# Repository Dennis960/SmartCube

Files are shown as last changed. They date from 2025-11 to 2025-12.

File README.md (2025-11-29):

# SmartCube

SmartCube is a modular, connectable LED cube platform. Each module is a small PCB containing addressable LEDs and sensors; modules mechanically and electrically connect using pogo pins and neodymium magnets. This monorepo contains KiCad PCB sources, a CadQuery 3D-model generator (that uses KiCad STEP exports), and firmware for the microcontrollers used across modules.

<!-- ![SmartCube](assets/cube.png)

TODO: Add image, once the cubes arrive -->

## Key features

- Modular PCB-based cube modules with addressable LEDs and Hall sensors
- Electrical connection via pogo pins; mechanical coupling via neodymium magnets
- ESP32 used as a power/aggregation/controller cube
- PY32 microcontrollers used for individual LED modules
- CadQuery scripts that generate printable enclosures using KiCad STEP references

## Project Structure

- [PCB](./PCB): KiCad projects for the LED module, power supply module and pogo pin connectors, as well as helper scripts for panelization.

- [3DModel](./3DModel): CadQuery scripts to generate 3D models of the cube modules and enclosures, using KiCad STEP exports as references.

- [Firmware](./Firmware): CMake-based firmware for the PY32 microcontrollers used in the LED modules, with support for flashing via ST-Link and esp-idf-based firmware for the ESP32 power/controller module.

A devcontainer exists for development for the 3DModel and panelization.

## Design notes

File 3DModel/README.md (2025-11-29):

# 3DModel

Generate and export 3D models of the SmartCube modules and enclosures using CadQuery scripts.

It is recommended to use the provided devcontainer for development, which includes all necessary dependencies.

Run

```bash
python main.py
```

inside the src folder to generate the models. The generated STEP files will be saved in the output folder.

## Troubleshooting

In case there is an issue with loading the kicad STEP files, delete the contents of the models folder and re-run the script to regenerate them.

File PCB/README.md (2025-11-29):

# PCB

This folder contains the KiCad projects for the SmartCube LED module, power supply module, and pogo pin connectors. It also includes helper scripts for panelization of the PCBs for manufacturing.

The KiCad projects all use the same shared library located in the `libs` folder.

If having problems loading footprints or 3d models, make sure to add the symbol and CustomFootprints libraries in KiCad.

## Module

[./Module](./Module) contains the KiCad project for the main LED module PCB.

It includes addressable LEDs and Hall sensors.
Communication happens via PY32 microcontrollers using pogo pin connectors.

## Power Module

[./PowerModule](./PowerModule) contains the KiCad project for the power supply module PCB.

It provides 5V power to the cubes via pogo pin connectors.

At least one power module is required in a SmartCube assembly to provide power to the other modules.

## Pogo Pin Connectors

[./PogoConnectors](./PogoConnectors) contains the KiCad projects for the pogo pin connectors.

It is used to connect the modules both mechanically and electrically.

## Panelization

[./Panel](./Panel) contains scripts to panelize the PCBs for manufacturing. The panelization uses the kikit tool.

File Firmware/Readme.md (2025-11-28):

# Firmware

This project provides a CMake-based setup for building firmware for the PY32F0 microcontrollers. It also supports flashing via ST-Link.
It is taken from [https://github.com/decaday/py32f0-cmake](https://github.com/decaday/py32f0-cmake)

---

## Prerequisites

- **ARM GCC Toolchain** (`arm-none-eabi-gcc`) with `sudo apt install gcc-arm-none-eabi`
- **CMake** (≥3.13)
- **Make**
- **ST-Link utilities** (`st-flash` or `st-util`) with `sudo apt install stlink-tools`
- **Git** (to clone the repository)

---

## 1. Build Firmware Using CMake + Make

1. Generate Makefiles with CMake:

```bash
cmake -B build -S .
```

2. Compile the firmware:

```bash
make -C build
```

- Output firmware: `build/py32-cmake.elf` and `build/py32-cmake.bin`

---

## 2. Flash Firmware to the Board

Using **ST-Link**:

```bash
st-flash write build/py32-cmake.bin 0x8000000
```

- Replace `0x8000000` with your MCU’s flash base address if different.

Optional: use **st-util** for debugging with GDB:

```bash
st-util
```

---

## 3. VS Code Integration

This repository includes **VS Code tasks** and a **launch configuration** for convenience:

- **Tasks**: Automate building and flashing.
- **Launch configuration**: Debug firmware using GDB and ST-Link.

### Usage

1. Open the project in VS Code.
2. Use the **Command Palette → Run Task** to build or flash firmware.
3. Start `st-util` in a terminal for debugging:

```bash
st-util
```

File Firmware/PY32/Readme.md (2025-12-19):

# Firmware PY32

This project provides a CMake-based setup for building firmware for the PY32F0 microcontrollers. It also supports flashing via ST-Link.
It is taken from [https://github.com/decaday/py32f0-cmake](https://github.com/decaday/py32f0-cmake)

Have a look at [https://github.com/junglami/py32-platform/tree/main/Examples/PY32F002B/LL](https://github.com/junglami/py32-platform/tree/main/Examples/PY32F002B/LL) for example code using the LL drivers.
Have a look at [the official firmware package](https://www.puyasemi.com/download_path/%E5%BA%93%E5%87%BD%E6%95%B0%E4%B8%8E%E4%BE%8B%E7%A8%8B/MCU%20%E5%BE%AE%E5%A4%84%E7%90%86%E5%99%A8/PY32F002B_Firmware_V1.2.1.zi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) for examples using both the HAL and LL drivers.

---

## Prerequisites

See [InstallToolchain.md](InstallToolchain.md) for installation instructions of the ARM Embedded Toolchain.

- **CMake** (≥3.13)
- **Make**
- **ST-Link utilities** (`st-flash` or `st-util`) with `sudo apt install stlink-tools`
- **Git** (to clone the repository)

---

## 1. Build Firmware Using CMake + Make

1. Generate Makefiles with CMake:

```bash
cmake -B build -S .
```

2. Compile the firmware:

```bash
make -C build
```

- Output firmware: `build/py32-cmake.elf` and `build/py32-cmake.bin`

---

## 2. Flash Firmware to the Board

Using **ST-Link**:

```bash
st-flash write build/py32-cmake.bin 0x8000000
```

- Replace `0x8000000` with your MCU’s flash base address if different.

Optional: use **st-util** for debugging with GDB:

```bash
st-util
```

---

## 3. VS Code Integration

This repository includes **VS Code tasks** and a **launch configuration** for convenience:

- **Tasks**: Automate building and flashing.
- **Launch configuration**: Debug firmware using GDB and ST-Link.

### Usage

1. Open the project in VS Code.
2. Use the **Command Palette → Run Task** to build or flash firmware.
3. Start `st-util` in a terminal for debugging:

```bash
st-util
```

### Debug & Release
- Launch configs: The workspace includes launch configurations for both Release and Debug.
- Breakpoints: Use the Debug configuration to set and hit breakpoints during firmware execution.
- Note: Flashing and debugging can fail if the LEDs are set to full brightness; reduce LED brightness if you encounter issues or connect an external power source.

---

## 4. Timing Protocols

For detailed information about the communication protocols and timing specifications implemented in this firmware, refer to [cube_communication_protocol/main.pdf](cube_communication_protocol/main.pdf).

This document outlines:
- Protocol specifications for cube communication
- Timing requirements and constraints
- Signal timing diagrams
- Communication handshake procedures

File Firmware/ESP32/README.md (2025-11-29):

# Firmware ESP32

This project contains the firmware for the ESP32 microcontroller used in the SmartCube platform. It is built using the esp-idf framework.

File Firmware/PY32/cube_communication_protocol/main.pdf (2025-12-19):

## 1 Timing protocols

The smart cubes communicate using a custom protocol over two data lines. Each cube has two data lines, D1 and D2. The data lines are only used for communication between cubes. Note that the cube’s data lines are inverted, meaning D1 of cube A is connected to D2 of cube B and vice versa.

### 1.1 Announcement

The announcement is used to connect a new cube inside a powered grid of cubes. The new cube will announce its presence to one side, starting at the first side (top). If another cube is present at that side, it will acknowledge the announcement of the new cube and a handshake will be performed. During the handshake, both cubes will check both their data lines for connection.
If presence is not acknowledged or the handshake fails, the new cube will retry the announcement on the next side.
The following timing diagram shows the digital signals. The Bus in the following diagram represents the actual state of the data lines of cube A. The data lines of cube A and cube B show their respective internal signals. A state of high impedance implies that the pin for that cube is set as input.

Bus 1

Bus 2

Cube A D1

ack presence

Cube A D2

ack handshake

Cube B D2

complete handshake

Cube B D1

announce

init handshake

Note

delay ≤ 10 ms

1

### 1.2 Data transfer (initiation)

When two cubes are successfully connected, they are in the idle state. Either cube can initiate data transfer to the other cube by asking for a communication. If the data initiation process is successful, the cube that asked for communication can start sending data.
The first byte of data sent is always the length of the data packet in bytes. The next bytes are the actual data bytes.
If the data specifies that a response is expected, the receiving cube will send a response packet back to the sender. Else the communication is finished and the cubes return to idle state.
The following timing diagram shows the digital signals. The Bus in the following diagram represents the actual state of the data lines of cube A. The data lines of cube A and cube B show their respective internal signals. A state of high impedance implies that the pin for that cube is set as input.

Bus 1

Bus 2

Cube A D1

Cube A D2

Cube B D2

Cube B D1

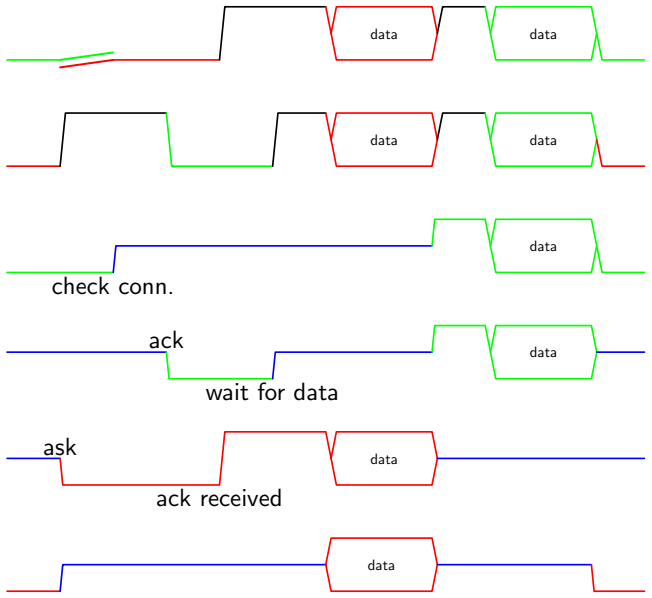
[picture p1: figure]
data; check conn.; ack; wait for data; ask; ack received

### 1.3 Data transfer

When the data transfer initiation succeeds, data can be transferred. This process uses one line as a clock and the other line for sending data bit by bit. The following timing diagram shows the digital signals for a short example data transfer. The bits are read on falling edges of the clock. Therefore, the data line must be stable before the falling edge of the clock and can change after the rising edge.

2

Bus 1 (clock)

Bus 2 (data)

Data bits | 1 | 0 | 0 | 1 | 0 | 1 | 1 | 1

3

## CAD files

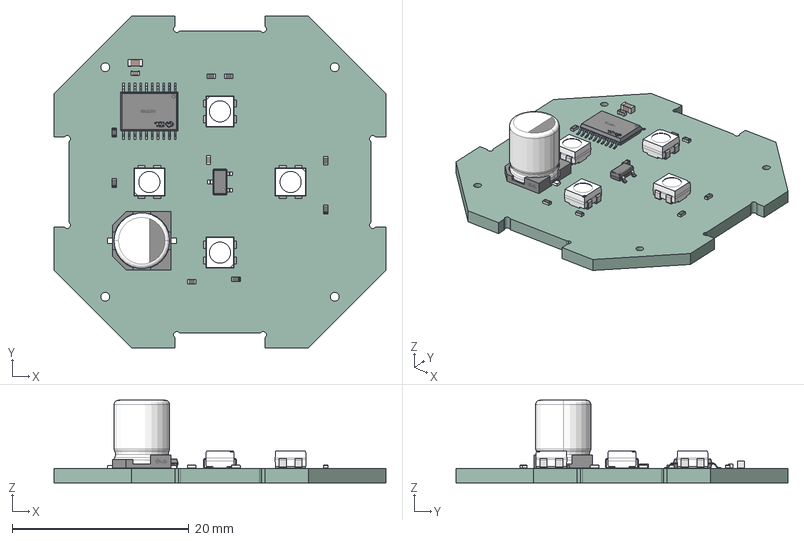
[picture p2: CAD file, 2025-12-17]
3DModel/models/Module.step
37.6 x 37.6 x 9.35 mm
SOT-23-3L_L2.9-W1.6-H1.1-LS2.8-P0.95
R_0402_1005Metric x 8
LED-SMD_4P-L3.5-W3.5-BR_SK6812MINI-HS x 4
C_0603_1608Metric
C_0402_1005Metric x 2
TSSOP-20_L6.5-W4.4-H1.0-LS6.4-P0.65
CAP-SMD_BD6.3-L6.6-W6.6-FD
Module_PCB

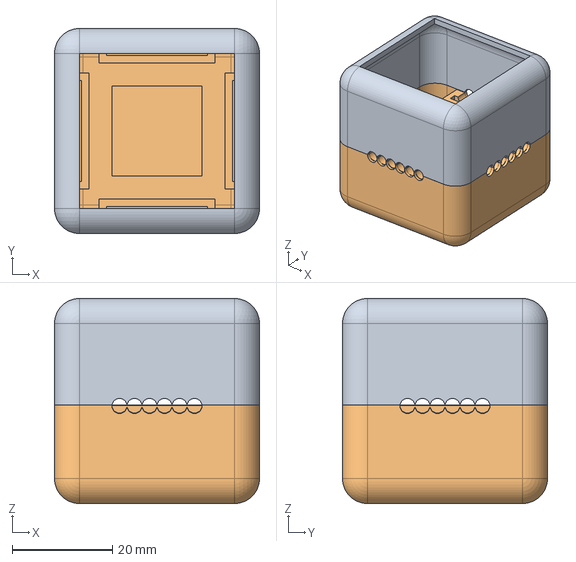
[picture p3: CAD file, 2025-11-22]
3DModel/SmartCube.FCStd
41.0 x 41.0 x 41.0 mm
BoxTop

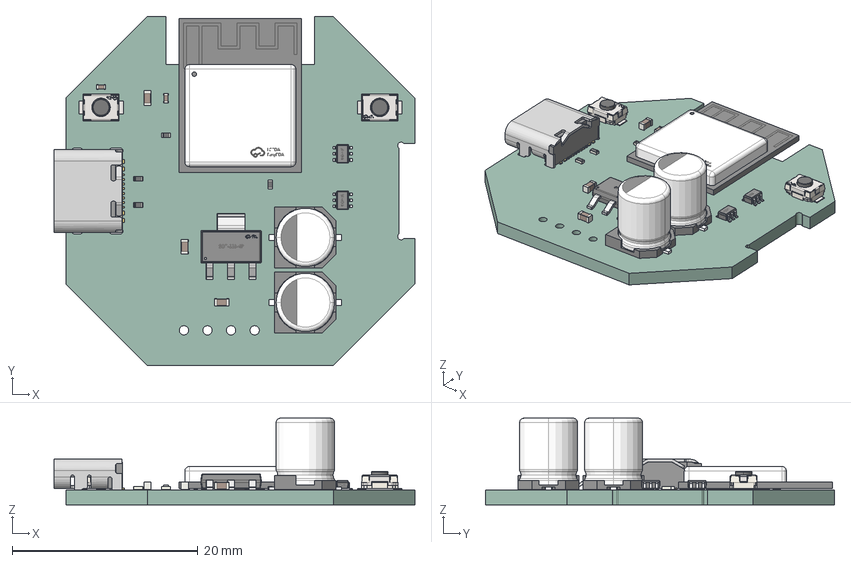
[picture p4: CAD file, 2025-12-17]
3DModel/models/PowerSupply.step
38.9 x 37.6 x 9.35 mm
SC-70-6_L2.0-W1.3-H1.0-P0.65 x 2
C_0603_1608Metric x 3
SOT-223-4P_L6.5-W3.5-H1.6-LS7.0-P2.30
R_0402_1005Metric x 4
USB-C-SMD_TYPE-C-6PIN-2MD-073
CAP-SMD_BD6.3-L6.6-W6.6-FD x 2
C_0402_1005Metric x 2
SW-SMD_L3.9-W2.9-H2.0-LS4.8 x 2
WIFIM-SMD_61P-L16.6-W13.2-P0.80-ESP32-C6-MINI-1-N4
PowerSupply_PCB

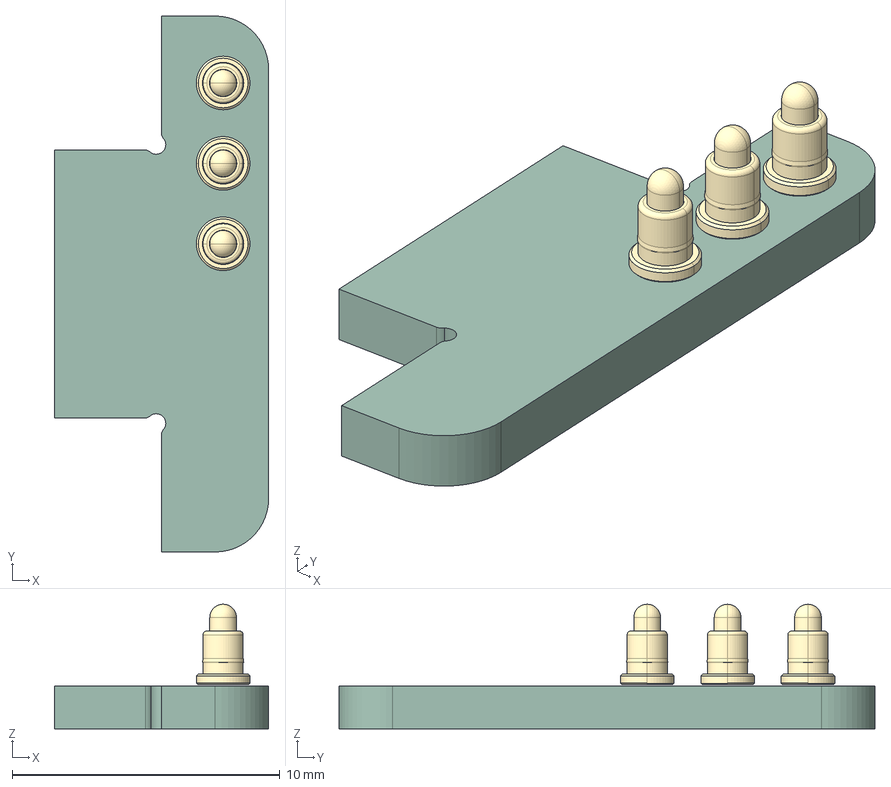
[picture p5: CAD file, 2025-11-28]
3DModel/models/PogoConnector.step
8.00 x 20.0 x 4.65 mm
零件1 x 3
PogoConnector_PCB

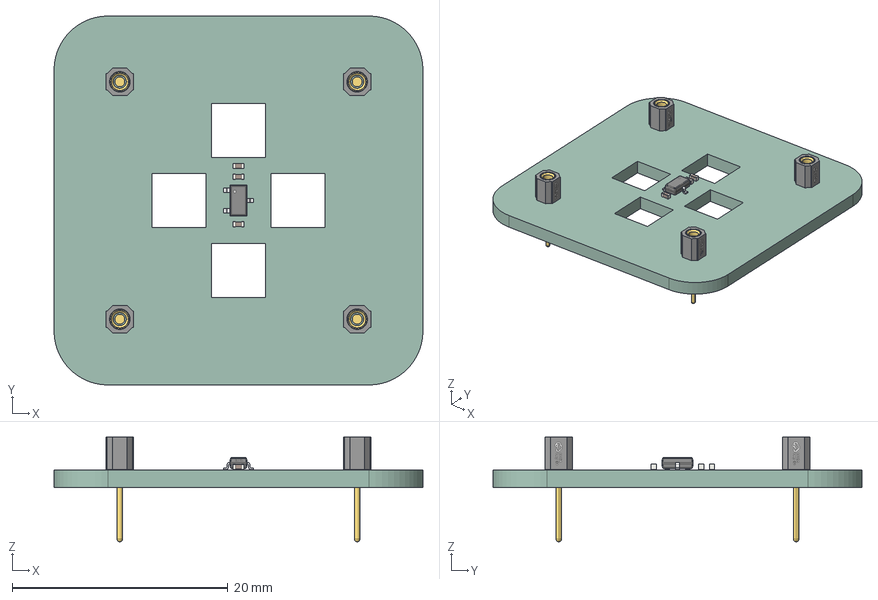
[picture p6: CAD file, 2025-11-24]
3DModel/models/ShieldHallSensor.step
34.2 x 34.2 x 9.70 mm
C_0402_1005Metric x 3
HDR-TH_1P-V-F-1 x 4
SOT-23-3L_L2.9-W1.6-H1.1-LS2.8-P0.95
ShieldHallSensor_PCB

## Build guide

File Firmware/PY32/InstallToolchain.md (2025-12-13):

## Manual ARM Embedded Toolchain Installation

> **Note:** ARM deprecated the PPA distribution method. All new packages are no longer released on Launchpad, requiring manual installation of the latest `arm-none-eabi-gdb`.

### 1. Remove existing package

```bash
sudo apt remove gcc-arm-none-eabi
```

### 2. Download and extract toolchain

Download the latest Linux x86_64 Tarball from [ARM's website](https://developer.arm.com/tools-and-software/open-source-software/developer-tools/gnu-toolchain/gnu-rm), verify its MD5, then extract:

```bash
sudo tar xjf gcc-arm-none-eabi-YOUR-VERSION.bz2 -C /usr/share/
```

### 3. Create system-wide symlinks

```bash
sudo ln -s /usr/share/gcc-arm-none-eabi-YOUR-VERSION/bin/arm-none-eabi-gcc /usr/bin/arm-none-eabi-gcc
sudo ln -s /usr/share/gcc-arm-none-eabi-YOUR-VERSION/bin/arm-none-eabi-g++ /usr/bin/arm-none-eabi-g++
sudo ln -s /usr/share/gcc-arm-none-eabi-YOUR-VERSION/bin/arm-none-eabi-gdb /usr/bin/arm-none-eabi-gdb
sudo ln -s /usr/share/gcc-arm-none-eabi-YOUR-VERSION/bin/arm-none-eabi-size /usr/bin/arm-none-eabi-size
sudo ln -s /usr/share/gcc-arm-none-eabi-YOUR-VERSION/bin/arm-none-eabi-objcopy /usr/bin/arm-none-eabi-objcopy
```

### 4. Install dependencies

```bash
sudo apt install libncurses-dev
sudo ln -s /usr/lib/x86_64-linux-gnu/libncurses.so.6 /usr/lib/x86_64-linux-gnu/libncurses.so.5
sudo ln -s /usr/lib/x86_64-linux-gnu/libtinfo.so.6 /usr/lib/x86_64-linux-gnu/libtinfo.so.5
```

### 5. Verify installation

```bash
arm-none-eabi-gcc --version
arm-none-eabi-g++ --version
arm-none-eabi-gdb --version
arm-none-eabi-size --version
```

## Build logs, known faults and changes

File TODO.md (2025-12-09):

- Put a large capacitor (e.g. 1000uF) on the power supply module or else there are inrush current issues when connecting new modules

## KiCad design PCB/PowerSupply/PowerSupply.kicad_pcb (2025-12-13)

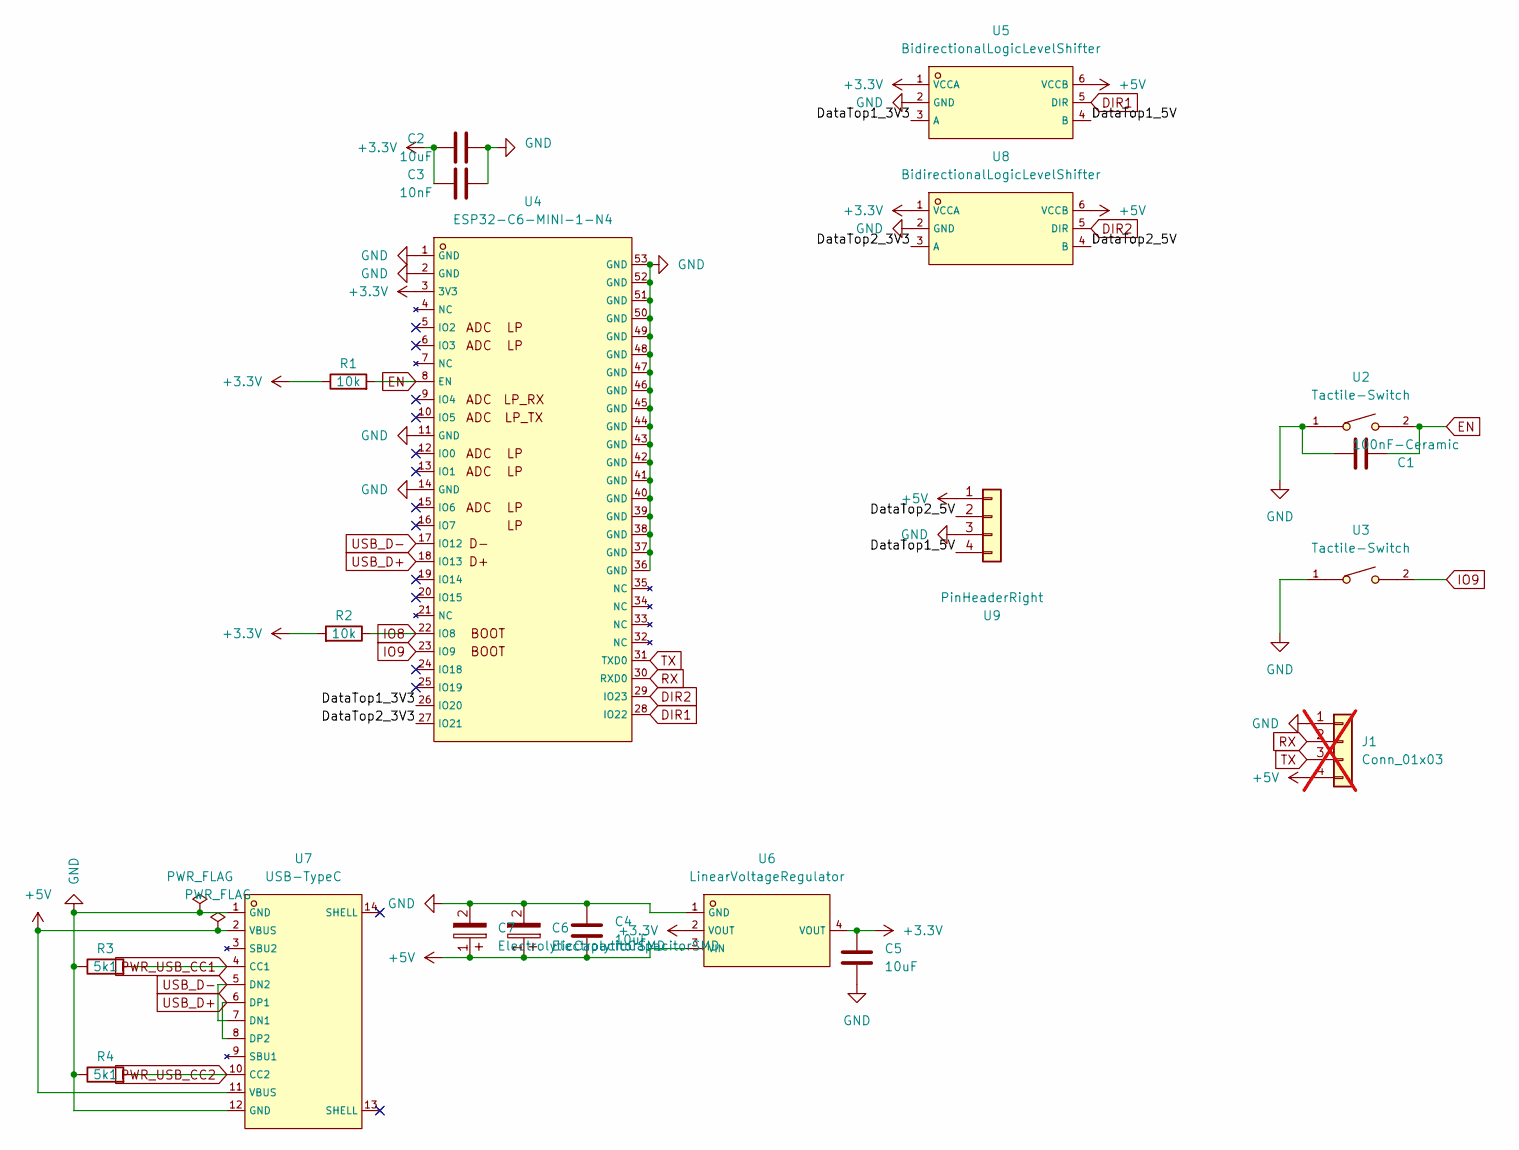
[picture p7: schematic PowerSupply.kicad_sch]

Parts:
C1: 100nF-Ceramic; C_0402_1005Metric; MPN C1525; LCSC C1525
C2: 10uF; C_0603_1608Metric; MPN C15525; LCSC C19702
C3: 10nF; C_0402_1005Metric; MPN C15195; LCSC C15195
C4, C5: 10uF; C_0603_1608Metric; LCSC C19702
C6, C7: ElectrolyticCapacitorSMD; CAP-SMD_BD6.3-L6.6-W6.6-FD; LCSC C335982
J1: Conn_01x03; PinHeader_1x04_P2.54mm_Vertical; MPN /; not fitted
R1, R2: 10k; R_0402_1005Metric; MPN C25744; LCSC C25744
R3, R4: 5k1; R_0402_1005Metric; MPN C25905; LCSC C25905
U2, U3: Tactile-Switch; Button; MPN C720477; LCSC C720477
U4: ESP32-C6-MINI-1-N4; ESP32C6-Mini-1-N4; LCSC C5736265
U5, U8: BidirectionalLogicLevelShifter; BidirectionalLogicLevelConverter; LCSC C168855
U6: LinearVoltageRegulator; VoltageRegulator; LCSC C6186
U7: USB-TypeC; USB-C-SMD_TYPE-C-6PIN-2MD-073; LCSC C2765186
U9: PinHeaderRight; 01x04_PinPads; LCSC C492414

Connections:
+3.3V: C2.1, C3.1, C5.1, R1.1, R2.2, U4.3 (3V3), U5.1 (VCCA), U6.2 (VOUT), U6.4 (VOUT), U8.1 (VCCA)
+5V: C4.2, C6.1, C7.1, J1.4, U5.6 (VCCB), U6.3 (VIN), U7.2 (VBUS), U7.11 (VBUS), U8.6 (VCCB), U9.1
/DataTop1_3V3: U4.26 (IO20), U5.3 (A)
/DataTop1_5V: U5.4 (B), U9.4
/DataTop2_3V3: U4.27 (IO21), U8.3 (A)
/DataTop2_5V: U8.4 (B), U9.2
DIR1: U4.28 (IO22), U5.5 (DIR)
DIR2: U4.29 (IO23), U8.5 (DIR)
EN: C1.1, R1.2, U2.2, U4.8 (EN)
GND: C1.2, C2.2, C3.2, C4.1, C5.2, C6.2, C7.2, J1.1, R3.1, R4.1, U2.1, U3.1, U4.1 (GND), U4.2 (GND), U4.11 (GND), U4.14 (GND), U4.36 (GND), U4.37 (GND), U4.38 (GND), U4.39 (GND), U4.40 (GND), U4.41 (GND), U4.42 (GND), U4.43 (GND), U4.44 (GND), U4.45 (GND), U4.46 (GND), U4.47 (GND), U4.48 (GND), U4.49 (GND), U4.50 (GND), U4.51 (GND), U4.52 (GND), U4.53 (GND), U5.2 (GND), U6.1 (GND), U7.1 (GND), U7.12 (GND), U8.2 (GND), U9.3
IO8: R2.1, U4.22 (IO8)
IO9: U3.2, U4.23 (IO9)
PWR_USB_CC1: R3.2, U7.4 (CC1)
PWR_USB_CC2: R4.2, U7.10 (CC2)
RX: J1.2, U4.30 (RXD0)
TX: J1.3, U4.31 (TXD0)
USB_D+: U4.18 (IO13), U7.6 (DP1), U7.8 (DP2)
USB_D-: U4.17 (IO12), U7.5 (DN2), U7.7 (DN1)

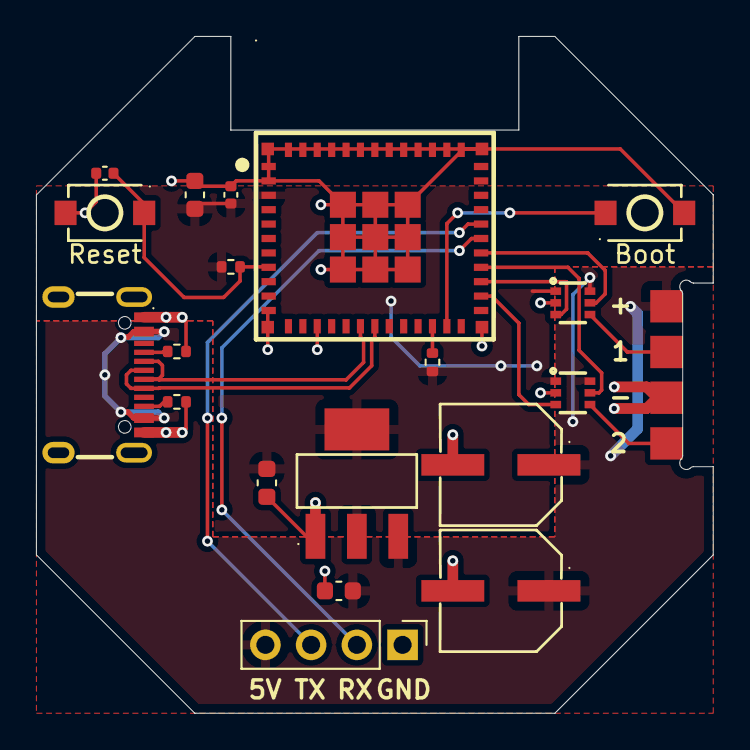
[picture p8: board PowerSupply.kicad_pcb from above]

Board: 2 copper layers, 37.6 x 37.6 mm, 20 parts (0 on the bottom side), 18 nets.

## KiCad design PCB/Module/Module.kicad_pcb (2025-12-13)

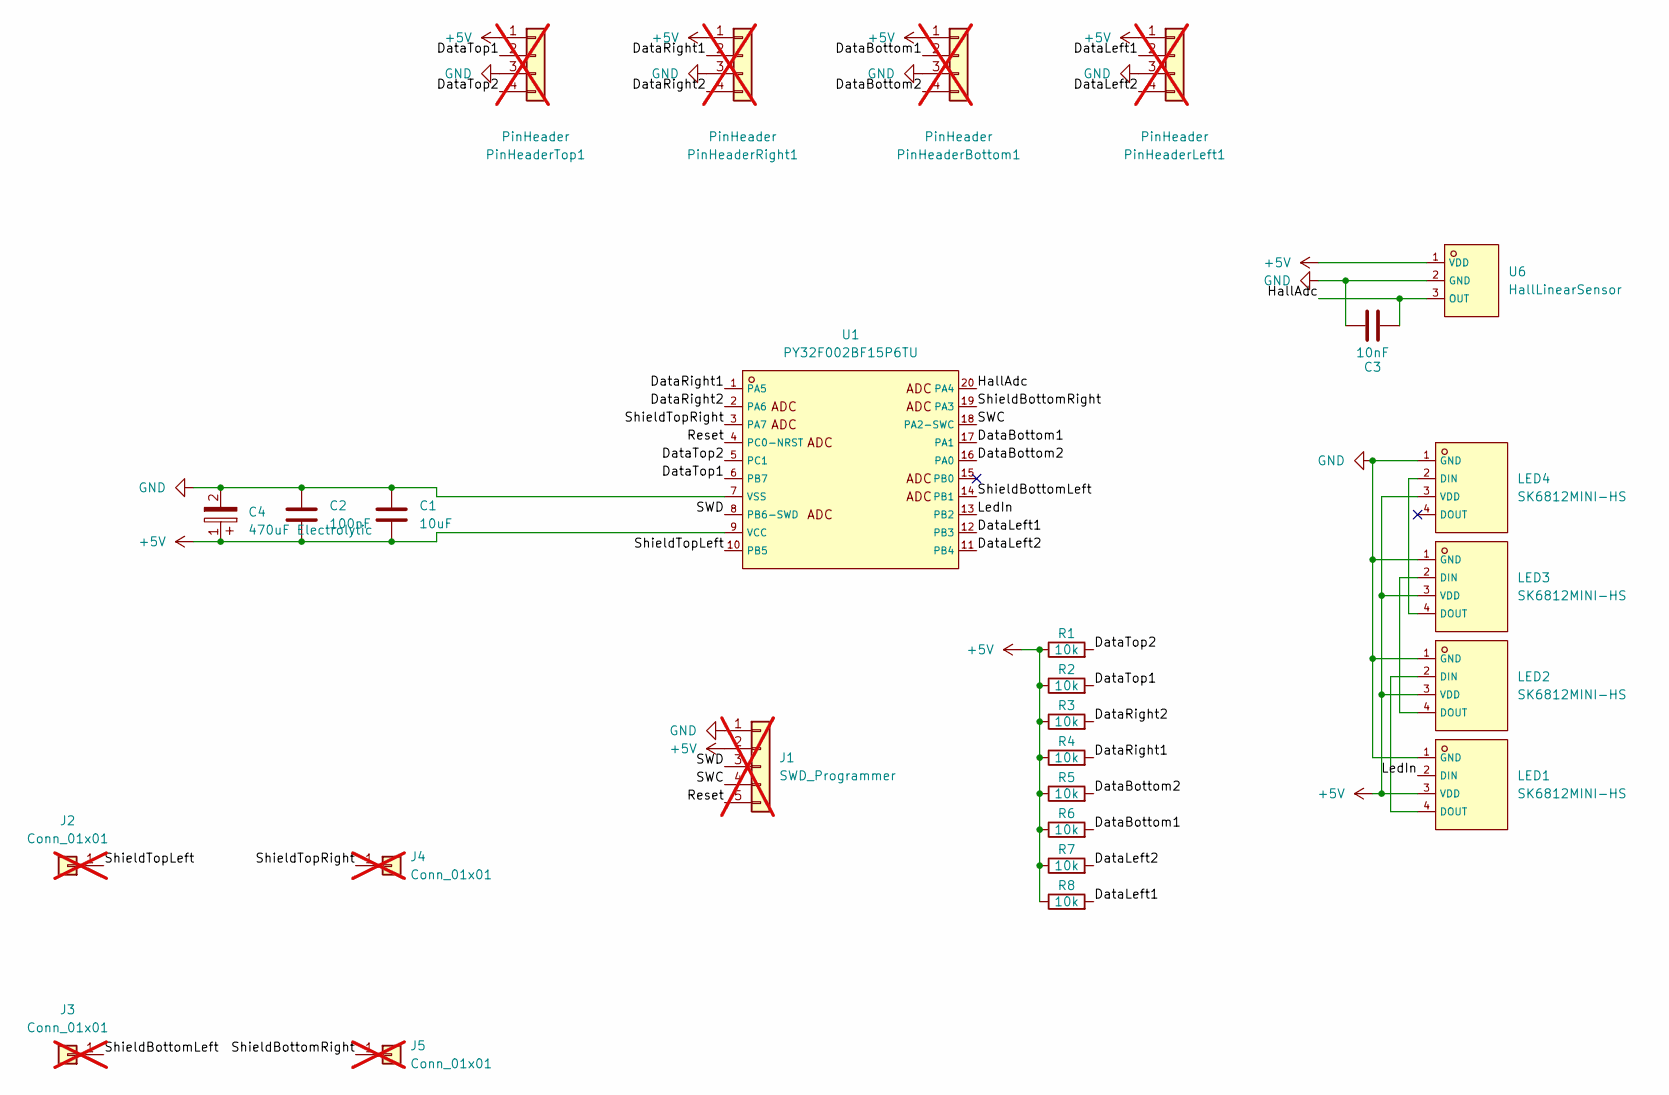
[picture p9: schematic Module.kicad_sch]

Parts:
C1: 10uF; C_0603_1608Metric; LCSC C19702
C2: 100nF; C_0402_1005Metric; LCSC C1525
C3: 10nF; C_0402_1005Metric; LCSC C15195
C4: 470uF Electrolytic; CAP-SMD_BD6.3-L6.6-W6.6-FD; LCSC C335982
J1: SWD_Programmer; SWD_Pad; not fitted
J2, J3, J4, J5: Conn_01x01; ShieldConnector; not fitted
LED1, LED2, LED3, LED4: SK6812MINI-HS; LED-SK6812MINI-HS; LCSC C2922787
PinHeaderBottom1: PinHeader; 01x04_PinPads; LCSC C492414; not fitted
PinHeaderLeft1: PinHeader; 01x04_PinPads; LCSC C492414; not fitted
PinHeaderRight1: PinHeader; 01x04_PinPads; LCSC C492414; not fitted
PinHeaderTop1: PinHeader; 01x04_PinPads; LCSC C492414; not fitted
R1, R2, R3, R4, R5, R6, R7, R8: 10k; R_0402_1005Metric; LCSC C25744
U1: PY32F002BF15P6TU; Py32; LCSC C7469098
U6: HallLinearSensor; LCSC C7420984

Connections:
+5V: C1.2, C2.2, C4.1, J1.2, LED1.3 (VDD), LED2.3 (VDD), LED3.3 (VDD), LED4.3 (VDD), PinHeaderBottom1.1, PinHeaderLeft1.1, PinHeaderRight1.1, PinHeaderTop1.1, R1.1, R2.1, R3.1, R4.1, R5.1, R6.1, R7.1, R8.1, U1.9 (VCC), U6.1 (VDD)
/DataBottom1: PinHeaderBottom1.2, R6.2, U1.17 (PA1)
/DataBottom2: PinHeaderBottom1.4, R5.2, U1.16 (PA0)
/DataLeft1: PinHeaderLeft1.2, R8.2, U1.12 (PB3)
/DataLeft2: PinHeaderLeft1.4, R7.2, U1.11 (PB4)
/DataRight1: PinHeaderRight1.2, R4.2, U1.1 (PA5)
/DataRight2: PinHeaderRight1.4, R3.2, U1.2 (PA6)
/DataTop1: PinHeaderTop1.2, R2.2, U1.6 (PB7)
/DataTop2: PinHeaderTop1.4, R1.2, U1.5 (PC1)
/HallAdc: C3.2, U1.20 (PA4), U6.3 (OUT)
/LedIn: LED1.2 (DIN), U1.13 (PB2)
/Reset: J1.5, U1.4 (PC0-NRST)
/SWC: J1.4, U1.18 (PA2-SWC)
/SWD: J1.3, U1.8 (PB6-SWD)
/ShieldBottomLeft: J3.1, U1.14 (PB1)
/ShieldBottomRight: J5.1, U1.19 (PA3)
/ShieldTopLeft: J2.1, U1.10 (PB5)
/ShieldTopRight: J4.1, U1.3 (PA7)
GND: C1.1, C2.1, C3.1, C4.2, J1.1, LED1.1 (GND), LED2.1 (GND), LED3.1 (GND), LED4.1 (GND), PinHeaderBottom1.3, PinHeaderLeft1.3, PinHeaderRight1.3, PinHeaderTop1.3, U1.7 (VSS), U6.2 (GND)
unnamed: LED1.4 (DOUT), LED2.2 (DIN)
unnamed: LED2.4 (DOUT), LED3.2 (DIN)
unnamed: LED3.4 (DOUT), LED4.2 (DIN)

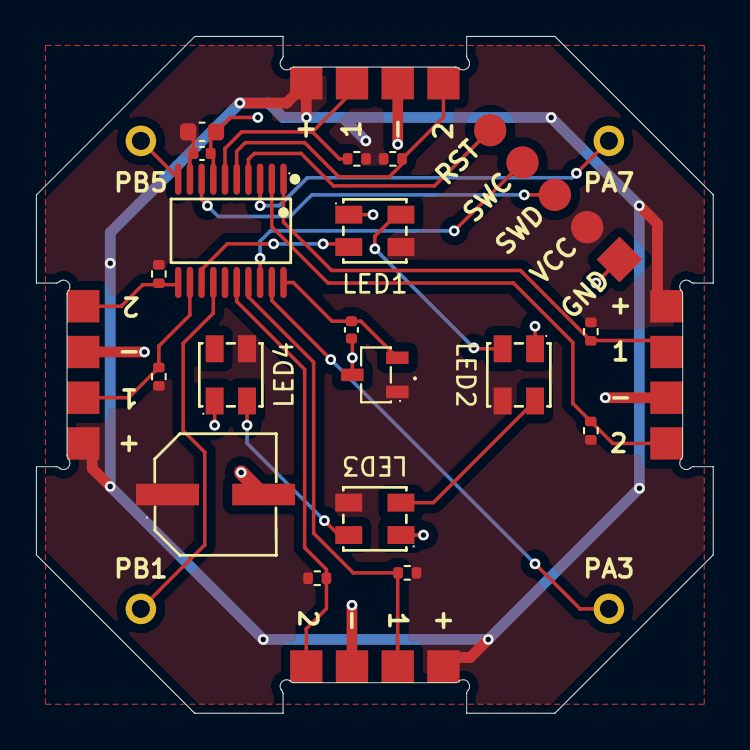
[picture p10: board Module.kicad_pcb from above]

Board: 2 copper layers, 37.6 x 37.6 mm, 27 parts (0 on the bottom side), 22 nets.

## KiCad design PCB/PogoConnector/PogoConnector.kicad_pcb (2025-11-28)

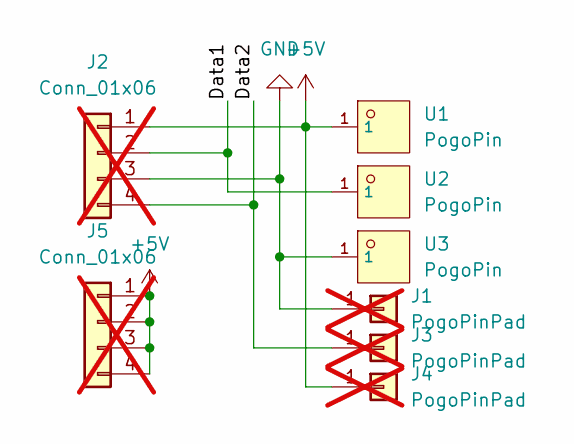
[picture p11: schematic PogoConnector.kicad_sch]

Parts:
J1, J3, J4: PogoPinPad; not fitted
J2, J5: Conn_01x06; 01x04_PinPads_Single; not fitted
U1, U2, U3: PogoPin; LCSC C2988082

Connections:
+5V: J2.1, J4.1, J5.1, J5.2, J5.3, J5.4, U1.1
/Data1: J2.2, U2.1
/Data2: J2.4, J3.1
GND: J1.1, J2.3, U3.1

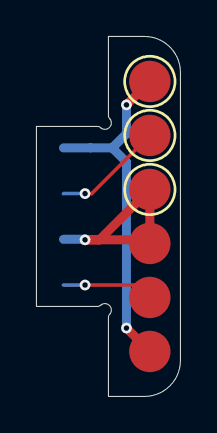
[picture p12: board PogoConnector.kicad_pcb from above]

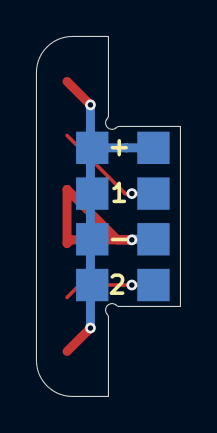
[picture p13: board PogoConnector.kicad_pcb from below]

Board: 2 copper layers, 8.0 x 20.0 mm, 8 parts (2 on the bottom side), 4 nets.

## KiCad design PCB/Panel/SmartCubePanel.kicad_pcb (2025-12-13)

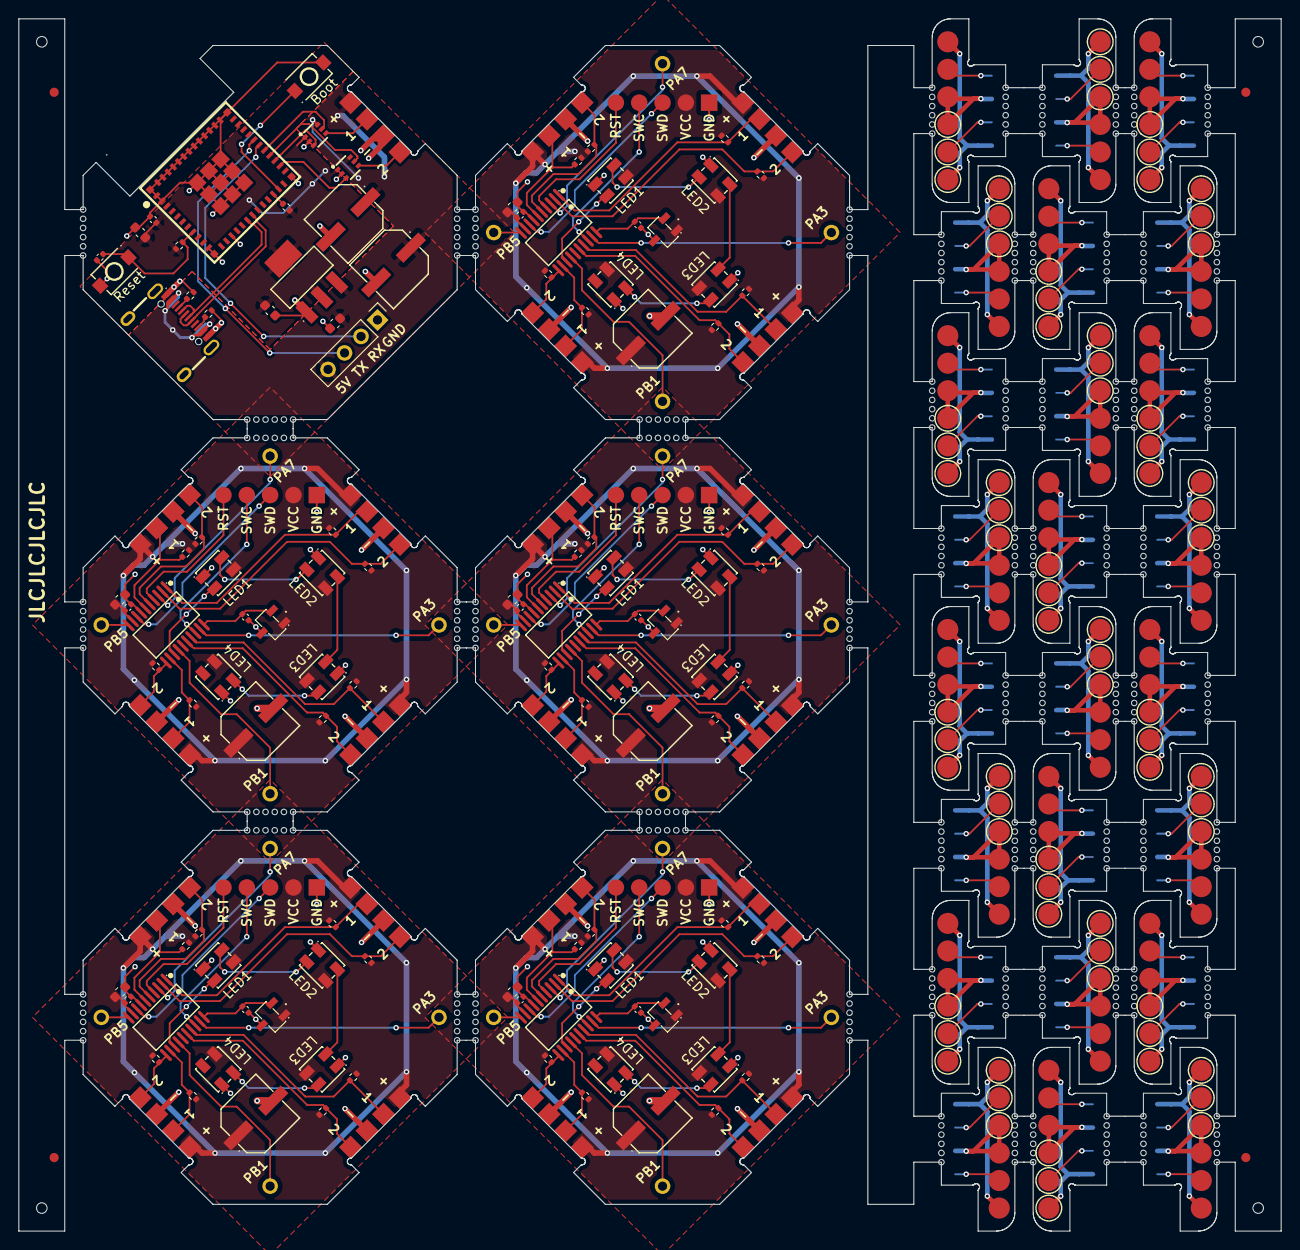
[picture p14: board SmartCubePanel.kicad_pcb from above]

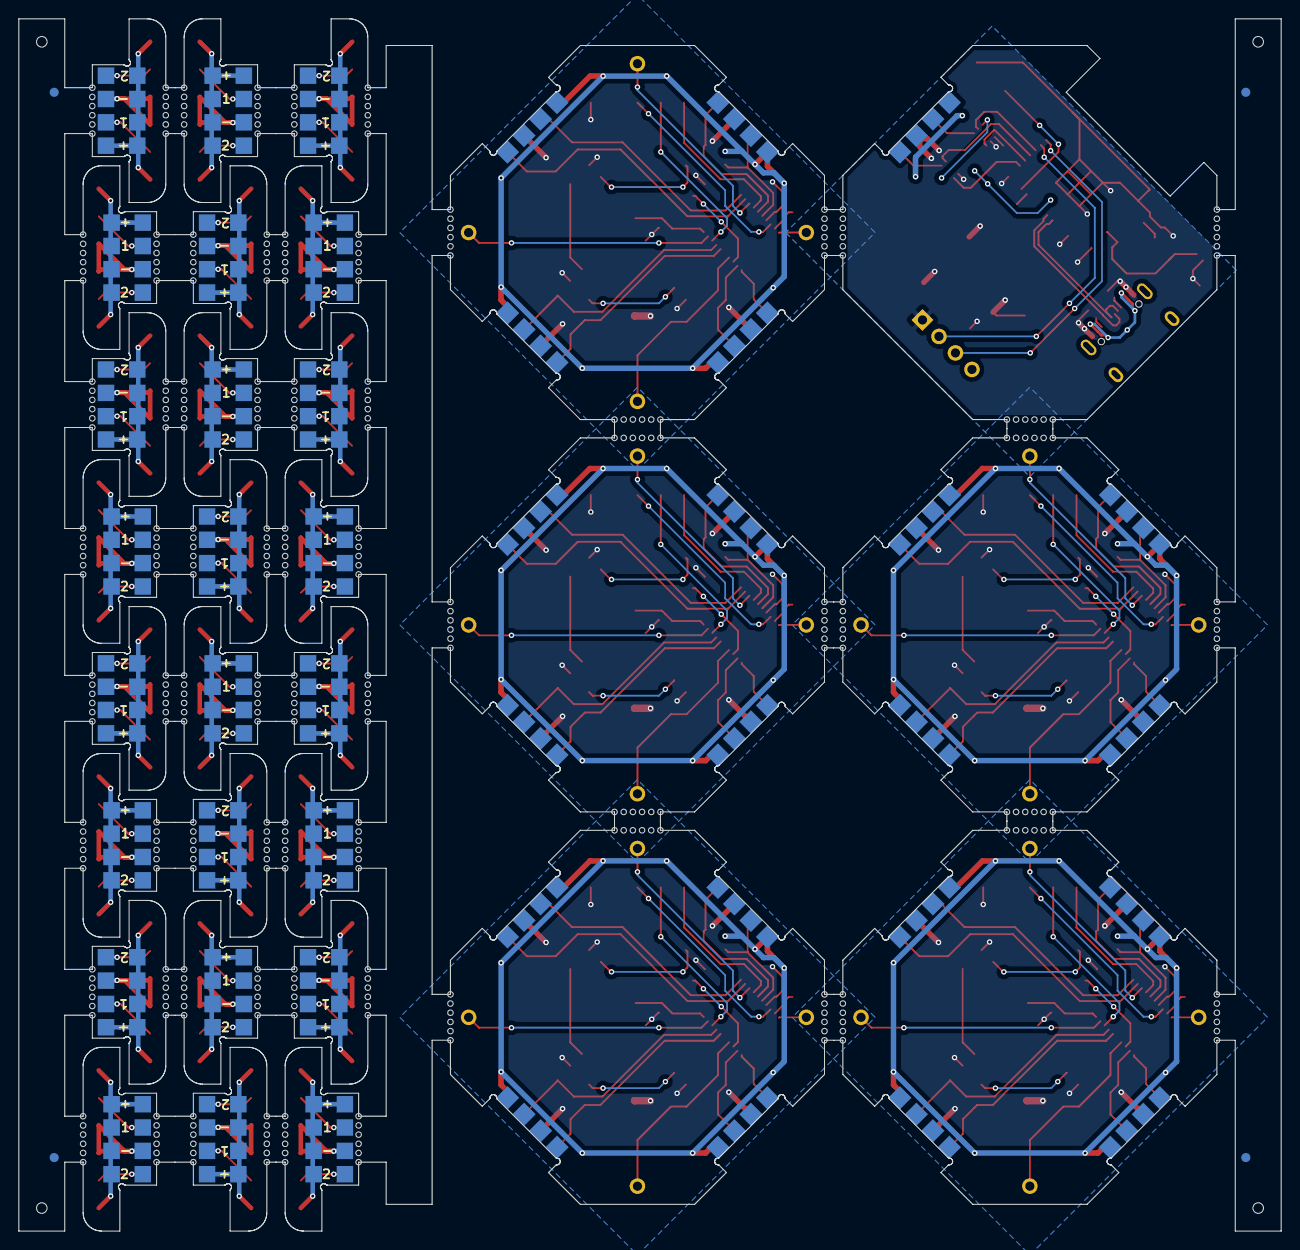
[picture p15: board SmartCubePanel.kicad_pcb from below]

Board: 2 copper layers, 137.5 x 132.0 mm, 767 parts (52 on the bottom side), 224 nets.

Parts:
KiKit_FID_B_1, KiKit_FID_B_2, KiKit_FID_B_3, KiKit_FID_B_4: Fiducial
KiKit_FID_T_1, KiKit_FID_T_2, KiKit_FID_T_3, KiKit_FID_T_4: Fiducial
KiKit_MB_1_1, KiKit_MB_1_2, KiKit_MB_1_3, KiKit_MB_1_4, KiKit_MB_1_5, KiKit_MB_1_6, KiKit_MB_2_1, KiKit_MB_2_2, KiKit_MB_2_3, KiKit_MB_2_4, KiKit_MB_2_5, KiKit_MB_2_6, KiKit_MB_3_1, KiKit_MB_3_2, KiKit_MB_3_3, KiKit_MB_3_4, KiKit_MB_3_5, KiKit_MB_3_6, KiKit_MB_4_1, KiKit_MB_4_2, KiKit_MB_4_3, KiKit_MB_4_4, KiKit_MB_4_5, KiKit_MB_4_6, KiKit_MB_5_1, KiKit_MB_5_2, KiKit_MB_5_3, KiKit_MB_5_4, KiKit_MB_5_5, KiKit_MB_5_6, KiKit_MB_6_1, KiKit_MB_6_2, KiKit_MB_6_3, KiKit_MB_6_4, KiKit_MB_6_5, KiKit_MB_6_6, KiKit_MB_7_1, KiKit_MB_7_2, KiKit_MB_7_3, KiKit_MB_7_4, KiKit_MB_7_5, KiKit_MB_7_6, KiKit_MB_8_1, KiKit_MB_8_2, KiKit_MB_8_3, KiKit_MB_8_4, KiKit_MB_8_5, KiKit_MB_8_6, KiKit_MB_9_1, KiKit_MB_9_2, KiKit_MB_9_3, KiKit_MB_9_4, KiKit_MB_9_5, KiKit_MB_9_6, KiKit_MB_10_1, KiKit_MB_10_2, KiKit_MB_10_3, KiKit_MB_10_4, KiKit_MB_10_5, KiKit_MB_10_6, KiKit_MB_11_1, KiKit_MB_11_2, KiKit_MB_11_3, KiKit_MB_11_4, KiKit_MB_11_5, KiKit_MB_11_6, KiKit_MB_12_1, KiKit_MB_12_2, KiKit_MB_12_3, KiKit_MB_12_4, KiKit_MB_12_5, KiKit_MB_12_6, KiKit_MB_13_1, KiKit_MB_13_2, KiKit_MB_13_3, KiKit_MB_13_4, KiKit_MB_13_5, KiKit_MB_13_6, KiKit_MB_14_1, KiKit_MB_14_2, KiKit_MB_14_3, KiKit_MB_14_4, KiKit_MB_14_5, KiKit_MB_14_6, KiKit_MB_15_1, KiKit_MB_15_2, KiKit_MB_15_3, KiKit_MB_15_4, KiKit_MB_15_5, KiKit_MB_15_6, KiKit_MB_16_1, KiKit_MB_16_2, KiKit_MB_16_3, KiKit_MB_16_4, KiKit_MB_16_5, KiKit_MB_16_6, KiKit_MB_17_1, KiKit_MB_17_2, KiKit_MB_17_3, KiKit_MB_17_4, KiKit_MB_17_5, KiKit_MB_17_6, KiKit_MB_18_1, KiKit_MB_18_2, KiKit_MB_18_3, KiKit_MB_18_4, KiKit_MB_18_5, KiKit_MB_18_6, KiKit_MB_19_1, KiKit_MB_19_2, KiKit_MB_19_3, KiKit_MB_19_4, KiKit_MB_19_5, KiKit_MB_19_6, KiKit_MB_20_1, KiKit_MB_20_2, KiKit_MB_20_3, KiKit_MB_20_4, KiKit_MB_20_5, KiKit_MB_20_6, KiKit_MB_21_1, KiKit_MB_21_2, KiKit_MB_21_3, KiKit_MB_21_4, KiKit_MB_21_5, KiKit_MB_21_6, KiKit_MB_22_1, KiKit_MB_22_2, KiKit_MB_22_3, KiKit_MB_22_4, KiKit_MB_22_5, KiKit_MB_22_6, KiKit_MB_23_1, KiKit_MB_23_2, KiKit_MB_23_3, KiKit_MB_23_4, KiKit_MB_23_5, KiKit_MB_23_6, KiKit_MB_24_1, KiKit_MB_24_2, KiKit_MB_24_3, KiKit_MB_24_4, KiKit_MB_24_5, KiKit_MB_24_6, KiKit_MB_25_1, KiKit_MB_25_2, KiKit_MB_25_3, KiKit_MB_25_4, KiKit_MB_25_5, KiKit_MB_25_6, KiKit_MB_26_1, KiKit_MB_26_2, KiKit_MB_26_3, KiKit_MB_26_4, KiKit_MB_26_5, KiKit_MB_26_6, KiKit_MB_27_1, KiKit_MB_27_2, KiKit_MB_27_3, KiKit_MB_27_4, KiKit_MB_27_5, KiKit_MB_27_6, KiKit_MB_28_1, KiKit_MB_28_2, KiKit_MB_28_3, KiKit_MB_28_4, KiKit_MB_28_5, KiKit_MB_28_6, KiKit_MB_29_1, KiKit_MB_29_2, KiKit_MB_29_3, KiKit_MB_29_4, KiKit_MB_29_5, KiKit_MB_29_6, KiKit_MB_30_1, KiKit_MB_30_2, KiKit_MB_30_3, KiKit_MB_30_4, KiKit_MB_30_5, KiKit_MB_30_6, KiKit_MB_31_1, KiKit_MB_31_2, KiKit_MB_31_3, KiKit_MB_31_4, KiKit_MB_31_5, KiKit_MB_31_6, KiKit_MB_32_1, KiKit_MB_32_2, KiKit_MB_32_3, KiKit_MB_32_4, KiKit_MB_32_5, KiKit_MB_32_6, KiKit_MB_33_1, KiKit_MB_33_2, KiKit_MB_33_3, KiKit_MB_33_4, KiKit_MB_33_5, KiKit_MB_33_6, KiKit_MB_34_1, KiKit_MB_34_2, KiKit_MB_34_3, KiKit_MB_34_4, KiKit_MB_34_5, KiKit_MB_34_6, KiKit_MB_35_1, KiKit_MB_35_2, KiKit_MB_35_3, KiKit_MB_35_4, KiKit_MB_35_5, KiKit_MB_35_6, KiKit_MB_36_1, KiKit_MB_36_2, KiKit_MB_36_3, KiKit_MB_36_4, KiKit_MB_36_5, KiKit_MB_36_6, KiKit_MB_37_1, KiKit_MB_37_2, KiKit_MB_37_3, KiKit_MB_37_4, KiKit_MB_37_5, KiKit_MB_37_6, KiKit_MB_38_1, KiKit_MB_38_2, KiKit_MB_38_3, KiKit_MB_38_4, KiKit_MB_38_5, KiKit_MB_38_6, KiKit_MB_39_1, KiKit_MB_39_2, KiKit_MB_39_3, KiKit_MB_39_4, KiKit_MB_39_5, KiKit_MB_39_6, KiKit_MB_40_1, KiKit_MB_40_2, KiKit_MB_40_3, KiKit_MB_40_4, KiKit_MB_40_5, KiKit_MB_40_6, KiKit_MB_41_1, KiKit_MB_41_2, KiKit_MB_41_3, KiKit_MB_41_4, KiKit_MB_41_5, KiKit_MB_41_6, KiKit_MB_42_1, KiKit_MB_42_2, KiKit_MB_42_3, KiKit_MB_42_4, KiKit_MB_42_5, KiKit_MB_42_6, KiKit_MB_43_1, KiKit_MB_43_2, KiKit_MB_43_3, KiKit_MB_43_4, KiKit_MB_43_5, KiKit_MB_43_6, KiKit_MB_44_1, KiKit_MB_44_2, KiKit_MB_44_3, KiKit_MB_44_4, KiKit_MB_44_5, KiKit_MB_44_6, KiKit_MB_45_1, KiKit_MB_45_2, KiKit_MB_45_3, KiKit_MB_45_4, KiKit_MB_45_5, KiKit_MB_45_6, KiKit_MB_46_1, KiKit_MB_46_2, KiKit_MB_46_3, KiKit_MB_46_4, KiKit_MB_46_5, KiKit_MB_46_6, KiKit_MB_47_1, KiKit_MB_47_2, KiKit_MB_47_3, KiKit_MB_47_4, KiKit_MB_47_5, KiKit_MB_47_6, KiKit_MB_48_1, KiKit_MB_48_2, KiKit_MB_48_3, KiKit_MB_48_4, KiKit_MB_48_5, KiKit_MB_48_6, KiKit_MB_49_1, KiKit_MB_49_2, KiKit_MB_49_3, KiKit_MB_49_4, KiKit_MB_49_5, KiKit_MB_49_6, KiKit_MB_50_1, KiKit_MB_50_2, KiKit_MB_50_3, KiKit_MB_50_4, KiKit_MB_50_5, KiKit_MB_50_6, KiKit_MB_51_1, KiKit_MB_51_2, KiKit_MB_51_3, KiKit_MB_51_4, KiKit_MB_51_5, KiKit_MB_51_6, KiKit_MB_52_1, KiKit_MB_52_2, KiKit_MB_52_3, KiKit_MB_52_4, KiKit_MB_52_5, KiKit_MB_52_6, KiKit_MB_53_1, KiKit_MB_53_2, KiKit_MB_53_3, KiKit_MB_53_4, KiKit_MB_53_5, KiKit_MB_53_6, KiKit_MB_54_1, KiKit_MB_54_2, KiKit_MB_54_3, KiKit_MB_54_4, KiKit_MB_54_5, KiKit_MB_54_6, KiKit_MB_55_1, KiKit_MB_55_2, KiKit_MB_55_3, KiKit_MB_55_4, KiKit_MB_55_5, KiKit_MB_55_6, KiKit_MB_56_1, KiKit_MB_56_2, KiKit_MB_56_3, KiKit_MB_56_4, KiKit_MB_56_5, KiKit_MB_56_6, KiKit_MB_57_1, KiKit_MB_57_2, KiKit_MB_57_3, KiKit_MB_57_4, KiKit_MB_57_5, KiKit_MB_57_6, KiKit_MB_58_1, KiKit_MB_58_2, KiKit_MB_58_3, KiKit_MB_58_4, KiKit_MB_58_5, KiKit_MB_58_6, KiKit_MB_59_1, KiKit_MB_59_2, KiKit_MB_59_3, KiKit_MB_59_4, KiKit_MB_59_5, KiKit_MB_59_6, KiKit_MB_60_1, KiKit_MB_60_2, KiKit_MB_60_3, KiKit_MB_60_4, KiKit_MB_60_5, KiKit_MB_60_6, KiKit_MB_61_1, KiKit_MB_61_2, KiKit_MB_61_3, KiKit_MB_61_4, KiKit_MB_61_5, KiKit_MB_61_6, KiKit_MB_62_1, KiKit_MB_62_2, KiKit_MB_62_3, KiKit_MB_62_4, KiKit_MB_62_5, KiKit_MB_62_6, KiKit_MB_63_1, KiKit_MB_63_2, KiKit_MB_63_3, KiKit_MB_63_4, KiKit_MB_63_5, KiKit_MB_63_6, KiKit_MB_64_1, KiKit_MB_64_2, KiKit_MB_64_3, KiKit_MB_64_4, KiKit_MB_64_5, KiKit_MB_64_6, KiKit_MB_65_1, KiKit_MB_65_2, KiKit_MB_65_3, KiKit_MB_65_4, KiKit_MB_65_5, KiKit_MB_65_6, KiKit_MB_66_1, KiKit_MB_66_2, KiKit_MB_66_3, KiKit_MB_66_4, KiKit_MB_66_5, KiKit_MB_66_6, KiKit_MB_67_1, KiKit_MB_67_2, KiKit_MB_67_3, KiKit_MB_67_4, KiKit_MB_67_5, KiKit_MB_67_6, KiKit_MB_68_1, KiKit_MB_68_2, KiKit_MB_68_3, KiKit_MB_68_4, KiKit_MB_68_5, KiKit_MB_68_6: NPTH
KiKit_TO_1, KiKit_TO_2, KiKit_TO_3, KiKit_TO_4: NPTH
M_1_C1, M_2_C1, M_3_C1, M_4_C1, M_5_C1: 10uF; C_0603_1608Metric
M_1_C2, M_2_C2, M_3_C2, M_4_C2, M_5_C2: 100nF; C_0402_1005Metric
M_1_C3, M_2_C3, M_3_C3, M_4_C3, M_5_C3: 10nF; C_0402_1005Metric
M_1_C4, M_2_C4, M_3_C4, M_4_C4, M_5_C4: 470uF Electrolytic; CAP-SMD_BD6.3-L6.6-W6.6-FD
M_1_J1, M_2_J1, M_3_J1, M_4_J1, M_5_J1: SWD_Programmer; SWD_Pad
M_1_J2, M_1_J3, M_1_J4, M_1_J5, M_2_J2, M_2_J3, M_2_J4, M_2_J5, M_3_J2, M_3_J3, M_3_J4, M_3_J5, M_4_J2, M_4_J3, M_4_J4, M_4_J5, M_5_J2, M_5_J3, M_5_J4, M_5_J5: Conn_01x01; ShieldConnector
M_1_LED1, M_1_LED2, M_1_LED3, M_1_LED4, M_2_LED1, M_2_LED2, M_2_LED3, M_2_LED4, M_3_LED1, M_3_LED2, M_3_LED3, M_3_LED4, M_4_LED1, M_4_LED2, M_4_LED3, M_4_LED4, M_5_LED1, M_5_LED2, M_5_LED3, M_5_LED4: SK6812MINI-HS; LED-SK6812MINI-HS
M_1_PinHeaderBottom1, M_1_PinHeaderLeft1, M_1_PinHeaderRight1, M_1_PinHeaderTop1, M_2_PinHeaderBottom1, M_2_PinHeaderLeft1, M_2_PinHeaderRight1, M_2_PinHeaderTop1, M_3_PinHeaderBottom1, M_3_PinHeaderLeft1, M_3_PinHeaderRight1, M_3_PinHeaderTop1, M_4_PinHeaderBottom1, M_4_PinHeaderLeft1, M_4_PinHeaderRight1, M_4_PinHeaderTop1, M_5_PinHeaderBottom1, M_5_PinHeaderLeft1, M_5_PinHeaderRight1, M_5_PinHeaderTop1: PinHeader; 01x04_PinPads
M_1_R1, M_1_R2, M_1_R3, M_1_R4, M_1_R5, M_1_R6, M_1_R7, M_1_R8, M_2_R1, M_2_R2, M_2_R3, M_2_R4, M_2_R5, M_2_R6, M_2_R7, M_2_R8, M_3_R1, M_3_R2, M_3_R3, M_3_R4, M_3_R5, M_3_R6, M_3_R7, M_3_R8, M_4_R1, M_4_R2, M_4_R3, M_4_R4, M_4_R5, M_4_R6, M_4_R7, M_4_R8, M_5_R1, M_5_R2, M_5_R3, M_5_R4, M_5_R5, M_5_R6, M_5_R7, M_5_R8: 10k; R_0402_1005Metric
M_1_U1, M_2_U1, M_3_U1, M_4_U1, M_5_U1: PY32F002BF15P6TU; Py32
M_1_U6, M_2_U6, M_3_U6, M_4_U6, M_5_U6: HallLinearSensor
POGO_6_J1, POGO_6_J3, POGO_6_J4, POGO_7_J1, POGO_7_J3, POGO_7_J4, POGO_8_J1, POGO_8_J3, POGO_8_J4, POGO_9_J1, POGO_9_J3, POGO_9_J4, POGO_10_J1, POGO_10_J3, POGO_10_J4, POGO_11_J1, POGO_11_J3, POGO_11_J4, POGO_12_J1, POGO_12_J3, POGO_12_J4, POGO_13_J1, POGO_13_J3, POGO_13_J4, POGO_14_J1, POGO_14_J3, POGO_14_J4, POGO_15_J1, POGO_15_J3, POGO_15_J4, POGO_16_J1, POGO_16_J3, POGO_16_J4, POGO_17_J1, POGO_17_J3, POGO_17_J4, POGO_18_J1, POGO_18_J3, POGO_18_J4, POGO_19_J1, POGO_19_J3, POGO_19_J4, POGO_20_J1, POGO_20_J3, POGO_20_J4, POGO_21_J1, POGO_21_J3, POGO_21_J4, POGO_22_J1, POGO_22_J3, POGO_22_J4, POGO_23_J1, POGO_23_J3, POGO_23_J4, POGO_24_J1, POGO_24_J3, POGO_24_J4, POGO_25_J1, POGO_25_J3, POGO_25_J4, POGO_26_J1, POGO_26_J3, POGO_26_J4, POGO_27_J1, POGO_27_J3, POGO_27_J4, POGO_28_J1, POGO_28_J3, POGO_28_J4, POGO_29_J1, POGO_29_J3, POGO_29_J4: PogoPinPad
POGO_6_J2, POGO_6_J5, POGO_7_J2, POGO_7_J5, POGO_8_J2, POGO_8_J5, POGO_9_J2, POGO_9_J5, POGO_10_J2, POGO_10_J5, POGO_11_J2, POGO_11_J5, POGO_12_J2, POGO_12_J5, POGO_13_J2, POGO_13_J5, POGO_14_J2, POGO_14_J5, POGO_15_J2, POGO_15_J5, POGO_16_J2, POGO_16_J5, POGO_17_J2, POGO_17_J5, POGO_18_J2, POGO_18_J5, POGO_19_J2, POGO_19_J5, POGO_20_J2, POGO_20_J5, POGO_21_J2, POGO_21_J5, POGO_22_J2, POGO_22_J5, POGO_23_J2, POGO_23_J5, POGO_24_J2, POGO_24_J5, POGO_25_J2, POGO_25_J5, POGO_26_J2, POGO_26_J5, POGO_27_J2, POGO_27_J5, POGO_28_J2, POGO_28_J5, POGO_29_J2, POGO_29_J5: Conn_01x06; 01x04_PinPads_Single
POGO_6_U1, POGO_6_U2, POGO_6_U3, POGO_7_U1, POGO_7_U2, POGO_7_U3, POGO_8_U1, POGO_8_U2, POGO_8_U3, POGO_9_U1, POGO_9_U2, POGO_9_U3, POGO_10_U1, POGO_10_U2, POGO_10_U3, POGO_11_U1, POGO_11_U2, POGO_11_U3, POGO_12_U1, POGO_12_U2, POGO_12_U3, POGO_13_U1, POGO_13_U2, POGO_13_U3, POGO_14_U1, POGO_14_U2, POGO_14_U3, POGO_15_U1, POGO_15_U2, POGO_15_U3, POGO_16_U1, POGO_16_U2, POGO_16_U3, POGO_17_U1, POGO_17_U2, POGO_17_U3, POGO_18_U1, POGO_18_U2, POGO_18_U3, POGO_19_U1, POGO_19_U2, POGO_19_U3, POGO_20_U1, POGO_20_U2, POGO_20_U3, POGO_21_U1, POGO_21_U2, POGO_21_U3, POGO_22_U1, POGO_22_U2, POGO_22_U3, POGO_23_U1, POGO_23_U2, POGO_23_U3, POGO_24_U1, POGO_24_U2, POGO_24_U3, POGO_25_U1, POGO_25_U2, POGO_25_U3, POGO_26_U1, POGO_26_U2, POGO_26_U3, POGO_27_U1, POGO_27_U2, POGO_27_U3, POGO_28_U1, POGO_28_U2, POGO_28_U3, POGO_29_U1, POGO_29_U2, POGO_29_U3: PogoPin
PSU_0_C1: 100nF-Ceramic; C_0402_1005Metric
PSU_0_C2, PSU_0_C4, PSU_0_C5: 10uF; C_0603_1608Metric
PSU_0_C3: 10nF; C_0402_1005Metric
PSU_0_C6, PSU_0_C7: ElectrolyticCapacitorSMD; CAP-SMD_BD6.3-L6.6-W6.6-FD
PSU_0_J1: Conn_01x03; PinHeader_1x04_P2.54mm_Vertical
PSU_0_R1, PSU_0_R2: 10k; R_0402_1005Metric
PSU_0_R3, PSU_0_R4: 5k1; R_0402_1005Metric
PSU_0_U2, PSU_0_U3: Tactile-Switch; Button
PSU_0_U4: ESP32-C6-MINI-1-N4; ESP32C6-Mini-1-N4
PSU_0_U5, PSU_0_U8: BidirectionalLogicLevelShifter; BidirectionalLogicLevelConverter
PSU_0_U6: LinearVoltageRegulator; VoltageRegulator
PSU_0_U7: USB-TypeC; USB-C-SMD_TYPE-C-6PIN-2MD-073
PSU_0_U9: PinHeaderRight; 01x04_PinPads

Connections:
Board_0-+3.3V: PSU_0_C2.1, PSU_0_C3.1, PSU_0_C5.1, PSU_0_R1.1, PSU_0_R2.2, PSU_0_U4.3 (3V3), PSU_0_U5.1 (VCCA), PSU_0_U6.2 (VOUT), PSU_0_U6.4 (VOUT), PSU_0_U8.1 (VCCA)
Board_0-+5V: PSU_0_C4.2, PSU_0_C6.1, PSU_0_C7.1, PSU_0_J1.4, PSU_0_U5.6 (VCCB), PSU_0_U6.3 (VIN), PSU_0_U7.2 (VBUS), PSU_0_U7.11 (VBUS), PSU_0_U8.6 (VCCB), PSU_0_U9.1
Board_0-/DataTop1_3V3: PSU_0_U4.26 (IO20), PSU_0_U5.3 (A)
Board_0-/DataTop1_5V: PSU_0_U5.4 (B), PSU_0_U9.4
Board_0-/DataTop2_3V3: PSU_0_U4.27 (IO21), PSU_0_U8.3 (A)
Board_0-/DataTop2_5V: PSU_0_U8.4 (B), PSU_0_U9.2
Board_0-DIR1: PSU_0_U4.28 (IO22), PSU_0_U5.5 (DIR)
Board_0-DIR2: PSU_0_U4.29 (IO23), PSU_0_U8.5 (DIR)
Board_0-EN: PSU_0_C1.1, PSU_0_R1.2, PSU_0_U2.2, PSU_0_U4.8 (EN)
Board_0-GND: PSU_0_C1.2, PSU_0_C2.2, PSU_0_C3.2, PSU_0_C4.1, PSU_0_C5.2, PSU_0_C6.2, PSU_0_C7.2, PSU_0_J1.1, PSU_0_R3.1, PSU_0_R4.1, PSU_0_U2.1, PSU_0_U3.1, PSU_0_U4.1 (GND), PSU_0_U4.2 (GND), PSU_0_U4.11 (GND), PSU_0_U4.14 (GND), PSU_0_U4.36 (GND), PSU_0_U4.37 (GND), PSU_0_U4.38 (GND), PSU_0_U4.39 (GND), PSU_0_U4.40 (GND), PSU_0_U4.41 (GND), PSU_0_U4.42 (GND), PSU_0_U4.43 (GND), PSU_0_U4.44 (GND), PSU_0_U4.45 (GND), PSU_0_U4.46 (GND), PSU_0_U4.47 (GND), PSU_0_U4.48 (GND), PSU_0_U4.49 (GND), PSU_0_U4.50 (GND), PSU_0_U4.51 (GND), PSU_0_U4.52 (GND), PSU_0_U4.53 (GND), PSU_0_U5.2 (GND), PSU_0_U6.1 (GND), PSU_0_U7.1 (GND), PSU_0_U7.12 (GND), PSU_0_U8.2 (GND), PSU_0_U9.3
Board_0-IO8: PSU_0_R2.1, PSU_0_U4.22 (IO8)
Board_0-IO9: PSU_0_U3.2, PSU_0_U4.23 (IO9)
Board_0-PWR_USB_CC1: PSU_0_R3.2, PSU_0_U7.4 (CC1)
Board_0-PWR_USB_CC2: PSU_0_R4.2, PSU_0_U7.10 (CC2)
Board_0-RX: PSU_0_J1.2, PSU_0_U4.30 (RXD0)
Board_0-TX: PSU_0_J1.3, PSU_0_U4.31 (TXD0)
Board_0-USB_D+: PSU_0_U4.18 (IO13), PSU_0_U7.6 (DP1), PSU_0_U7.8 (DP2)
Board_0-USB_D-: PSU_0_U4.17 (IO12), PSU_0_U7.5 (DN2), PSU_0_U7.7 (DN1)
Board_1-+5V: M_1_C1.2, M_1_C2.2, M_1_C4.1, M_1_J1.2, M_1_LED1.3 (VDD), M_1_LED2.3 (VDD), M_1_LED3.3 (VDD), M_1_LED4.3 (VDD), M_1_PinHeaderBottom1.1, M_1_PinHeaderLeft1.1, M_1_PinHeaderRight1.1, M_1_PinHeaderTop1.1, M_1_R1.1, M_1_R2.1, M_1_R3.1, M_1_R4.1, M_1_R5.1, M_1_R6.1, M_1_R7.1, M_1_R8.1, M_1_U1.9 (VCC), M_1_U6.1 (VDD)
Board_1-/DataBottom1: M_1_PinHeaderBottom1.2, M_1_R6.2, M_1_U1.17 (PA1)
Board_1-/DataBottom2: M_1_PinHeaderBottom1.4, M_1_R5.2, M_1_U1.16 (PA0)
Board_1-/DataLeft1: M_1_PinHeaderLeft1.2, M_1_R8.2, M_1_U1.12 (PB3)
Board_1-/DataLeft2: M_1_PinHeaderLeft1.4, M_1_R7.2, M_1_U1.11 (PB4)
Board_1-/DataRight1: M_1_PinHeaderRight1.2, M_1_R4.2, M_1_U1.1 (PA5)
Board_1-/DataRight2: M_1_PinHeaderRight1.4, M_1_R3.2, M_1_U1.2 (PA6)
Board_1-/DataTop1: M_1_PinHeaderTop1.2, M_1_R2.2, M_1_U1.6 (PB7)
Board_1-/DataTop2: M_1_PinHeaderTop1.4, M_1_R1.2, M_1_U1.5 (PC1)
Board_1-/HallAdc: M_1_C3.2, M_1_U1.20 (PA4), M_1_U6.3 (OUT)
Board_1-/LedIn: M_1_LED1.2 (DIN), M_1_U1.13 (PB2)
Board_1-/Reset: M_1_J1.5, M_1_U1.4 (PC0-NRST)
Board_1-/SWC: M_1_J1.4, M_1_U1.18 (PA2-SWC)
Board_1-/SWD: M_1_J1.3, M_1_U1.8 (PB6-SWD)
Board_1-/ShieldBottomLeft: M_1_J3.1, M_1_U1.14 (PB1)
Board_1-/ShieldBottomRight: M_1_J5.1, M_1_U1.19 (PA3)
Board_1-/ShieldTopLeft: M_1_J2.1, M_1_U1.10 (PB5)
Board_1-/ShieldTopRight: M_1_J4.1, M_1_U1.3 (PA7)
Board_1-GND: M_1_C1.1, M_1_C2.1, M_1_C3.1, M_1_C4.2, M_1_J1.1, M_1_LED1.1 (GND), M_1_LED2.1 (GND), M_1_LED3.1 (GND), M_1_LED4.1 (GND), M_1_PinHeaderBottom1.3, M_1_PinHeaderLeft1.3, M_1_PinHeaderRight1.3, M_1_PinHeaderTop1.3, M_1_U1.7 (VSS), M_1_U6.2 (GND)
Board_1-Net-(LED1-DOUT): M_1_LED1.4 (DOUT), M_1_LED2.2 (DIN)
Board_1-Net-(LED2-DOUT): M_1_LED2.4 (DOUT), M_1_LED3.2 (DIN)
Board_1-Net-(LED3-DOUT): M_1_LED3.4 (DOUT), M_1_LED4.2 (DIN)
Board_2-+5V: M_2_C1.2, M_2_C2.2, M_2_C4.1, M_2_J1.2, M_2_LED1.3 (VDD), M_2_LED2.3 (VDD), M_2_LED3.3 (VDD), M_2_LED4.3 (VDD), M_2_PinHeaderBottom1.1, M_2_PinHeaderLeft1.1, M_2_PinHeaderRight1.1, M_2_PinHeaderTop1.1, M_2_R1.1, M_2_R2.1, M_2_R3.1, M_2_R4.1, M_2_R5.1, M_2_R6.1, M_2_R7.1, M_2_R8.1, M_2_U1.9 (VCC), M_2_U6.1 (VDD)
Board_2-/DataBottom1: M_2_PinHeaderBottom1.2, M_2_R6.2, M_2_U1.17 (PA1)
Board_2-/DataBottom2: M_2_PinHeaderBottom1.4, M_2_R5.2, M_2_U1.16 (PA0)
Board_2-/DataLeft1: M_2_PinHeaderLeft1.2, M_2_R8.2, M_2_U1.12 (PB3)
Board_2-/DataLeft2: M_2_PinHeaderLeft1.4, M_2_R7.2, M_2_U1.11 (PB4)
Board_2-/DataRight1: M_2_PinHeaderRight1.2, M_2_R4.2, M_2_U1.1 (PA5)
Board_2-/DataRight2: M_2_PinHeaderRight1.4, M_2_R3.2, M_2_U1.2 (PA6)
Board_2-/DataTop1: M_2_PinHeaderTop1.2, M_2_R2.2, M_2_U1.6 (PB7)
Board_2-/DataTop2: M_2_PinHeaderTop1.4, M_2_R1.2, M_2_U1.5 (PC1)
Board_2-/HallAdc: M_2_C3.2, M_2_U1.20 (PA4), M_2_U6.3 (OUT)
Board_2-/LedIn: M_2_LED1.2 (DIN), M_2_U1.13 (PB2)
Board_2-/Reset: M_2_J1.5, M_2_U1.4 (PC0-NRST)
Board_2-/SWC: M_2_J1.4, M_2_U1.18 (PA2-SWC)
Board_2-/SWD: M_2_J1.3, M_2_U1.8 (PB6-SWD)
Board_2-/ShieldBottomLeft: M_2_J3.1, M_2_U1.14 (PB1)
Board_2-/ShieldBottomRight: M_2_J5.1, M_2_U1.19 (PA3)
Board_2-/ShieldTopLeft: M_2_J2.1, M_2_U1.10 (PB5)
Board_2-/ShieldTopRight: M_2_J4.1, M_2_U1.3 (PA7)
Board_2-GND: M_2_C1.1, M_2_C2.1, M_2_C3.1, M_2_C4.2, M_2_J1.1, M_2_LED1.1 (GND), M_2_LED2.1 (GND), M_2_LED3.1 (GND), M_2_LED4.1 (GND), M_2_PinHeaderBottom1.3, M_2_PinHeaderLeft1.3, M_2_PinHeaderRight1.3, M_2_PinHeaderTop1.3, M_2_U1.7 (VSS), M_2_U6.2 (GND)
Board_2-Net-(LED1-DOUT): M_2_LED1.4 (DOUT), M_2_LED2.2 (DIN)
Board_2-Net-(LED2-DOUT): M_2_LED2.4 (DOUT), M_2_LED3.2 (DIN)
Board_2-Net-(LED3-DOUT): M_2_LED3.4 (DOUT), M_2_LED4.2 (DIN)
Board_3-+5V: M_3_C1.2, M_3_C2.2, M_3_C4.1, M_3_J1.2, M_3_LED1.3 (VDD), M_3_LED2.3 (VDD), M_3_LED3.3 (VDD), M_3_LED4.3 (VDD), M_3_PinHeaderBottom1.1, M_3_PinHeaderLeft1.1, M_3_PinHeaderRight1.1, M_3_PinHeaderTop1.1, M_3_R1.1, M_3_R2.1, M_3_R3.1, M_3_R4.1, M_3_R5.1, M_3_R6.1, M_3_R7.1, M_3_R8.1, M_3_U1.9 (VCC), M_3_U6.1 (VDD)
Board_3-/DataBottom1: M_3_PinHeaderBottom1.2, M_3_R6.2, M_3_U1.17 (PA1)
Board_3-/DataBottom2: M_3_PinHeaderBottom1.4, M_3_R5.2, M_3_U1.16 (PA0)
Board_3-/DataLeft1: M_3_PinHeaderLeft1.2, M_3_R8.2, M_3_U1.12 (PB3)
Board_3-/DataLeft2: M_3_PinHeaderLeft1.4, M_3_R7.2, M_3_U1.11 (PB4)
Board_3-/DataRight1: M_3_PinHeaderRight1.2, M_3_R4.2, M_3_U1.1 (PA5)
Board_3-/DataRight2: M_3_PinHeaderRight1.4, M_3_R3.2, M_3_U1.2 (PA6)
Board_3-/DataTop1: M_3_PinHeaderTop1.2, M_3_R2.2, M_3_U1.6 (PB7)
Board_3-/DataTop2: M_3_PinHeaderTop1.4, M_3_R1.2, M_3_U1.5 (PC1)
Board_3-/HallAdc: M_3_C3.2, M_3_U1.20 (PA4), M_3_U6.3 (OUT)
Board_3-/LedIn: M_3_LED1.2 (DIN), M_3_U1.13 (PB2)
Board_3-/Reset: M_3_J1.5, M_3_U1.4 (PC0-NRST)
Board_3-/SWC: M_3_J1.4, M_3_U1.18 (PA2-SWC)
Board_3-/SWD: M_3_J1.3, M_3_U1.8 (PB6-SWD)
Board_3-/ShieldBottomLeft: M_3_J3.1, M_3_U1.14 (PB1)
Board_3-/ShieldBottomRight: M_3_J5.1, M_3_U1.19 (PA3)
Board_3-/ShieldTopLeft: M_3_J2.1, M_3_U1.10 (PB5)
Board_3-/ShieldTopRight: M_3_J4.1, M_3_U1.3 (PA7)
Board_3-GND: M_3_C1.1, M_3_C2.1, M_3_C3.1, M_3_C4.2, M_3_J1.1, M_3_LED1.1 (GND), M_3_LED2.1 (GND), M_3_LED3.1 (GND), M_3_LED4.1 (GND), M_3_PinHeaderBottom1.3, M_3_PinHeaderLeft1.3, M_3_PinHeaderRight1.3, M_3_PinHeaderTop1.3, M_3_U1.7 (VSS), M_3_U6.2 (GND)
Board_3-Net-(LED1-DOUT): M_3_LED1.4 (DOUT), M_3_LED2.2 (DIN)
Board_3-Net-(LED2-DOUT): M_3_LED2.4 (DOUT), M_3_LED3.2 (DIN)
Board_3-Net-(LED3-DOUT): M_3_LED3.4 (DOUT), M_3_LED4.2 (DIN)
Board_4-+5V: M_4_C1.2, M_4_C2.2, M_4_C4.1, M_4_J1.2, M_4_LED1.3 (VDD), M_4_LED2.3 (VDD), M_4_LED3.3 (VDD), M_4_LED4.3 (VDD), M_4_PinHeaderBottom1.1, M_4_PinHeaderLeft1.1, M_4_PinHeaderRight1.1, M_4_PinHeaderTop1.1, M_4_R1.1, M_4_R2.1, M_4_R3.1, M_4_R4.1, M_4_R5.1, M_4_R6.1, M_4_R7.1, M_4_R8.1, M_4_U1.9 (VCC), M_4_U6.1 (VDD)
Board_4-/DataBottom1: M_4_PinHeaderBottom1.2, M_4_R6.2, M_4_U1.17 (PA1)
Board_4-/DataBottom2: M_4_PinHeaderBottom1.4, M_4_R5.2, M_4_U1.16 (PA0)
Board_4-/DataLeft1: M_4_PinHeaderLeft1.2, M_4_R8.2, M_4_U1.12 (PB3)
Board_4-/DataLeft2: M_4_PinHeaderLeft1.4, M_4_R7.2, M_4_U1.11 (PB4)
Board_4-/DataRight1: M_4_PinHeaderRight1.2, M_4_R4.2, M_4_U1.1 (PA5)
Board_4-/DataRight2: M_4_PinHeaderRight1.4, M_4_R3.2, M_4_U1.2 (PA6)
Board_4-/DataTop1: M_4_PinHeaderTop1.2, M_4_R2.2, M_4_U1.6 (PB7)
Board_4-/DataTop2: M_4_PinHeaderTop1.4, M_4_R1.2, M_4_U1.5 (PC1)
Board_4-/HallAdc: M_4_C3.2, M_4_U1.20 (PA4), M_4_U6.3 (OUT)
Board_4-/LedIn: M_4_LED1.2 (DIN), M_4_U1.13 (PB2)
Board_4-/Reset: M_4_J1.5, M_4_U1.4 (PC0-NRST)
Board_4-/SWC: M_4_J1.4, M_4_U1.18 (PA2-SWC)
Board_4-/SWD: M_4_J1.3, M_4_U1.8 (PB6-SWD)
Board_4-/ShieldBottomLeft: M_4_J3.1, M_4_U1.14 (PB1)
Board_4-/ShieldBottomRight: M_4_J5.1, M_4_U1.19 (PA3)
Board_4-/ShieldTopLeft: M_4_J2.1, M_4_U1.10 (PB5)
Board_4-/ShieldTopRight: M_4_J4.1, M_4_U1.3 (PA7)
Board_4-GND: M_4_C1.1, M_4_C2.1, M_4_C3.1, M_4_C4.2, M_4_J1.1, M_4_LED1.1 (GND), M_4_LED2.1 (GND), M_4_LED3.1 (GND), M_4_LED4.1 (GND), M_4_PinHeaderBottom1.3, M_4_PinHeaderLeft1.3, M_4_PinHeaderRight1.3, M_4_PinHeaderTop1.3, M_4_U1.7 (VSS), M_4_U6.2 (GND)
Board_4-Net-(LED1-DOUT): M_4_LED1.4 (DOUT), M_4_LED2.2 (DIN)
Board_4-Net-(LED2-DOUT): M_4_LED2.4 (DOUT), M_4_LED3.2 (DIN)
Board_4-Net-(LED3-DOUT): M_4_LED3.4 (DOUT), M_4_LED4.2 (DIN)
Board_5-+5V: M_5_C1.2, M_5_C2.2, M_5_C4.1, M_5_J1.2, M_5_LED1.3 (VDD), M_5_LED2.3 (VDD), M_5_LED3.3 (VDD), M_5_LED4.3 (VDD), M_5_PinHeaderBottom1.1, M_5_PinHeaderLeft1.1, M_5_PinHeaderRight1.1, M_5_PinHeaderTop1.1, M_5_R1.1, M_5_R2.1, M_5_R3.1, M_5_R4.1, M_5_R5.1, M_5_R6.1, M_5_R7.1, M_5_R8.1, M_5_U1.9 (VCC), M_5_U6.1 (VDD)
Board_5-/DataBottom1: M_5_PinHeaderBottom1.2, M_5_R6.2, M_5_U1.17 (PA1)
Board_5-/DataBottom2: M_5_PinHeaderBottom1.4, M_5_R5.2, M_5_U1.16 (PA0)
Board_5-/DataLeft1: M_5_PinHeaderLeft1.2, M_5_R8.2, M_5_U1.12 (PB3)
Board_5-/DataLeft2: M_5_PinHeaderLeft1.4, M_5_R7.2, M_5_U1.11 (PB4)
Board_5-/DataRight1: M_5_PinHeaderRight1.2, M_5_R4.2, M_5_U1.1 (PA5)
Board_5-/DataRight2: M_5_PinHeaderRight1.4, M_5_R3.2, M_5_U1.2 (PA6)
Board_5-/DataTop1: M_5_PinHeaderTop1.2, M_5_R2.2, M_5_U1.6 (PB7)
Board_5-/DataTop2: M_5_PinHeaderTop1.4, M_5_R1.2, M_5_U1.5 (PC1)
Board_5-/HallAdc: M_5_C3.2, M_5_U1.20 (PA4), M_5_U6.3 (OUT)
Board_5-/LedIn: M_5_LED1.2 (DIN), M_5_U1.13 (PB2)
Board_5-/Reset: M_5_J1.5, M_5_U1.4 (PC0-NRST)
Board_5-/SWC: M_5_J1.4, M_5_U1.18 (PA2-SWC)
Board_5-/SWD: M_5_J1.3, M_5_U1.8 (PB6-SWD)
Board_5-/ShieldBottomLeft: M_5_J3.1, M_5_U1.14 (PB1)
Board_5-/ShieldBottomRight: M_5_J5.1, M_5_U1.19 (PA3)
Board_5-/ShieldTopLeft: M_5_J2.1, M_5_U1.10 (PB5)
Board_5-/ShieldTopRight: M_5_J4.1, M_5_U1.3 (PA7)
Board_5-GND: M_5_C1.1, M_5_C2.1, M_5_C3.1, M_5_C4.2, M_5_J1.1, M_5_LED1.1 (GND), M_5_LED2.1 (GND), M_5_LED3.1 (GND), M_5_LED4.1 (GND), M_5_PinHeaderBottom1.3, M_5_PinHeaderLeft1.3, M_5_PinHeaderRight1.3, M_5_PinHeaderTop1.3, M_5_U1.7 (VSS), M_5_U6.2 (GND)
Board_5-Net-(LED1-DOUT): M_5_LED1.4 (DOUT), M_5_LED2.2 (DIN)
Board_5-Net-(LED2-DOUT): M_5_LED2.4 (DOUT), M_5_LED3.2 (DIN)
Board_5-Net-(LED3-DOUT): M_5_LED3.4 (DOUT), M_5_LED4.2 (DIN)
Board_6-+5V: POGO_6_J2.1, POGO_6_J4.1, POGO_6_J5.1, POGO_6_J5.2, POGO_6_J5.3, POGO_6_J5.4, POGO_6_U1.1
Board_6-/Data1: POGO_6_J2.2, POGO_6_U2.1
Board_6-/Data2: POGO_6_J2.4, POGO_6_J3.1
Board_6-GND: POGO_6_J1.1, POGO_6_J2.3, POGO_6_U3.1
Board_7-+5V: POGO_7_J2.1, POGO_7_J4.1, POGO_7_J5.1, POGO_7_J5.2, POGO_7_J5.3, POGO_7_J5.4, POGO_7_U1.1
Board_7-/Data1: POGO_7_J2.2, POGO_7_U2.1
Board_7-/Data2: POGO_7_J2.4, POGO_7_J3.1
Board_7-GND: POGO_7_J1.1, POGO_7_J2.3, POGO_7_U3.1
Board_8-+5V: POGO_8_J2.1, POGO_8_J4.1, POGO_8_J5.1, POGO_8_J5.2, POGO_8_J5.3, POGO_8_J5.4, POGO_8_U1.1
Board_8-/Data1: POGO_8_J2.2, POGO_8_U2.1
Board_8-/Data2: POGO_8_J2.4, POGO_8_J3.1
Board_8-GND: POGO_8_J1.1, POGO_8_J2.3, POGO_8_U3.1
Board_9-+5V: POGO_9_J2.1, POGO_9_J4.1, POGO_9_J5.1, POGO_9_J5.2, POGO_9_J5.3, POGO_9_J5.4, POGO_9_U1.1
Board_9-/Data1: POGO_9_J2.2, POGO_9_U2.1
Board_9-/Data2: POGO_9_J2.4, POGO_9_J3.1
Board_9-GND: POGO_9_J1.1, POGO_9_J2.3, POGO_9_U3.1
Board_10-+5V: POGO_10_J2.1, POGO_10_J4.1, POGO_10_J5.1, POGO_10_J5.2, POGO_10_J5.3, POGO_10_J5.4, POGO_10_U1.1
Board_10-/Data1: POGO_10_J2.2, POGO_10_U2.1
Board_10-/Data2: POGO_10_J2.4, POGO_10_J3.1
Board_10-GND: POGO_10_J1.1, POGO_10_J2.3, POGO_10_U3.1
Board_11-+5V: POGO_11_J2.1, POGO_11_J4.1, POGO_11_J5.1, POGO_11_J5.2, POGO_11_J5.3, POGO_11_J5.4, POGO_11_U1.1
Board_11-/Data1: POGO_11_J2.2, POGO_11_U2.1
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

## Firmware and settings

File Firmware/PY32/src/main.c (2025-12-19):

#include "setup/hardware.h"
#include "sk6812/sk6812.h"
#include "sk6812/sk6812_effects.h"
#include "sensors/hall.h"
#include "cube/cube.h"
#include "cube/cube_data.h"

position_data_t cube_position_data = {
    .origin_x = -1,
    .origin_y = 0,
    .x = 0,
    .y = 0,
};
cube_side_t cube_position_origin_side = CUBE_LEFT; // The side of this cube where the origin is located

void handle_hall_sensor_data_request(cube_side_t cube_side)
{
  cube_data_packet_t response_packet = {
      .type = DATA_TYPE_HALL_SENSOR_DATA,
      .data.hall_data = {
          .value = hall_read(),
      },
  };
  cube_send_data_packet(cube_side, &response_packet);
}

void handle_led_color_data_received(cube_side_t cube_side, led_color_data_t *led_data)
{
  for (uint8_t i = 0; i < 4; i++)
  {
    sk6812_set_pixel(i,
                     led_data->pixels[i][0],
                     led_data->pixels[i][1],
                     led_data->pixels[i][2]);
  }
}

void handle_hall_sensor_data_received(cube_side_t cube_side, hall_sensor_data_t *hall_data)
{
  float brightness = hall_data->value * hall_data->value; // Square for better contrast
  uint8_t color_value = (uint8_t)(brightness * 255.0f);
  sk6812_set_pixel(cube_side_to_index(cube_side), 0, 0, color_value);
}

void handle_position_data_request(cube_side_t cube_side)
{
  int8_t new_x, new_y;
  int8_t delta_x = cube_position_data.x - cube_position_data.origin_x;
  int8_t delta_y = cube_position_data.y - cube_position_data.origin_y;
  // Determine new position based on which side the request came from
  if (cube_side == cube_side_opposite(cube_position_origin_side))
  {
    new_x = cube_position_data.x + delta_x;
    new_y = cube_position_data.y + delta_y;
  }
  else if (cube_side == cube_side_rotate_clockwise(cube_position_origin_side))
  {
    new_x = cube_position_data.x - delta_y;
    new_y = cube_position_data.y + delta_x;
  }
  else if (cube_side == cube_side_rotate_counterclockwise(cube_position_origin_side))
  {
    new_x = cube_position_data.x + delta_y;
    new_y = cube_position_data.y - delta_x;
  }
  else
  {
    // Same side, return origin
    new_x = cube_position_data.origin_x;
    new_y = cube_position_data.origin_y;
  }
  cube_data_packet_t response_packet = {
      .type = DATA_TYPE_POSITION_DATA,
      .data.position_data = {
          .origin_x = cube_position_data.x,
          .origin_y = cube_position_data.y,
          .x = new_x,
          .y = new_y,
      },
  };
  cube_send_data_packet(cube_side, &response_packet);
}

void handle_position_data_received(cube_side_t cube_side, position_data_t *position_data)
{
  memcpy(&cube_position_data, position_data, sizeof(position_data_t));
  cube_position_origin_side = cube_side;
}

/**
 * Callback when data is received from another cube.
 * @param cube_side The side of the cube that sent the data
 * @param packet The received cube data packet
 */
void cube_data_received_callback(cube_side_t cube_side, cube_data_packet_t *packet)
{
  if (packet->type == DATA_TYPE_REQUEST_HALL_SENSOR_DATA)
  {
    handle_hall_sensor_data_request(cube_side);
  }
  else if (packet->type == DATA_TYPE_LED_COLOR)
  {
    handle_led_color_data_received(cube_side, &packet->data.led_data);
  }
  else if (packet->type == DATA_TYPE_HALL_SENSOR_DATA)
  {
    handle_hall_sensor_data_received(cube_side, &packet->data.hall_data);
  }
  else if (packet->type == DATA_TYPE_REQUEST_POSITION_DATA)
  {
    handle_position_data_request(cube_side);
  }
  else if (packet->type == DATA_TYPE_POSITION_DATA)
  {
    handle_position_data_received(cube_side, &packet->data.position_data);
  }
}

/**
 * Callback when an error occurs during communication in the cube_loop.
 * @param cube_side The side of the cube where the error occurred
 * @param status The status code, one of CUBE_DATA_TRANSMISSION_ERROR_DESERIALIZATION, CUBE_DATA_TRANSMISSION_ERROR_ACKNOWLEDGE_TIMEOUT, CUBE_DATA_TRANSMISSION_ERROR_ACKNOWLEDGE_RECEIVE_TIMEOUT, CUBE_DATA_TRANSMISSION_ERROR_ACKNOWLEDGE_FINISH_TIMEOUT, CUBE_DATA_TRANSMISSION_ERROR_CLOCK_TIMEOUT
 * @param packet The data packet involved in the error, if any, else NULL
 */
void cube_error_callback(cube_side_t cube_side, cube_data_transmission_status_t status, cube_data_packet_t *packet)
{
  if (status == CUBE_DATA_TRANSMISSION_ERROR_DESERIALIZATION)
    sk6812_show_binary_code(1);
  else if (status == CUBE_DATA_TRANSMISSION_ERROR_ACKNOWLEDGE_TIMEOUT)
    sk6812_show_binary_code(2);
  else if (status == CUBE_DATA_TRANSMISSION_ERROR_ACKNOWLEDGE_RECEIVE_TIMEOUT)
    sk6812_show_binary_code(3);
  else if (status == CUBE_DATA_TRANSMISSION_ERROR_ACKNOWLEDGE_FINISH_TIMEOUT)
    sk6812_show_binary_code(4);
  else if (status == CUBE_DATA_TRANSMISSION_ERROR_CLOCK_TIMEOUT)
    sk6812_show_binary_code(5);
  else
    sk6812_show_binary_code(0xF);
}

/**
 * Callback when a connection error occurs.
 * @param cube_side The side of the cube where the connection error occurred
 * @param status The connection status code, one of CUBE_CONNECTION_ERROR_ANNOUNCE_TIMEOUT, CUBE_CONNECTION_ERROR_ACKNOWLEDGE_PRESENCE_TIMEOUT, CUBE_CONNECTION_ERROR_INIT_HANDSHAKE_TIMEOUT, CUBE_CONNECTION_ERROR_ACKNOWLEDGE_HANDSHAKE_TIMEOUT, CUBE_CONNECTION_ERROR_COMPLETE_HANDSHAKE_TIMEOUT
 */
void cube_connection_error_callback(cube_side_t cube_side, cube_connection_status_t status)
{
  if (status == CUBE_CONNECTION_ERROR_ANNOUNCE_TIMEOUT)
    sk6812_show_binary_code(6);
  else if (status == CUBE_CONNECTION_ERROR_ACKNOWLEDGE_PRESENCE_TIMEOUT)
    sk6812_show_binary_code(7);
  else if (status == CUBE_CONNECTION_ERROR_INIT_HANDSHAKE_TIMEOUT)
    sk6812_show_binary_code(8);
  else if (status == CUBE_CONNECTION_ERROR_ACKNOWLEDGE_HANDSHAKE_TIMEOUT)
    sk6812_show_binary_code(9);
  else if (status == CUBE_CONNECTION_ERROR_COMPLETE_HANDSHAKE_TIMEOUT)
    sk6812_show_binary_code(10);
  else
    sk6812_show_binary_code(0xE);
}

/**
 * Callback when a cube is connected.
 * @param cube_side The side of the cube that was connected
 */
void cube_connected_callback(cube_side_t cube_side)
{
  // sk6812_set_pixel(cube_side_to_index(cube_side), 0, 1, 0);
}

/**
 * Callback when a cube is disconnected.
 * @param cube_side The side of the cube that was disconnected
 */
void cube_disconnected_callback(cube_side_t cube_side)
{
  // sk6812_set_pixel(cube_side_to_index(cube_side), 1, 0, 0);
}

int main(void)
{
  hardware_init();

  sk6812_init(GPIOB, LL_GPIO_PIN_2, 4);
  cube_hardware_init();
  hall_init();

  cube_set_data_callback(cube_data_received_callback);
  cube_set_error_callback(cube_error_callback);
  cube_set_connected_callback(cube_connected_callback);
  cube_set_disconnected_callback(cube_disconnected_callback);
  cube_set_connection_error_callback(cube_connection_error_callback);

  cube_side_t cube_side = wait_for_cube_connection();

  cube_data_packet_t request_position_packet = {
      .type = DATA_TYPE_REQUEST_POSITION_DATA,
  };
  cube_send_data_packet(cube_side, &request_position_packet);

  while (1)
  {
    cube_loop();
    // Debug: Show parent cube by white pixel and position by color
    uint8_t brightnesses[3] = {0xFF, 0x80, 0x00};
    int8_t sum = cube_position_data.x + cube_position_data.y;
    uint8_t index = ((sum % 3) + 3) % 3;
    sk6812_fill(brightnesses[index],
                brightnesses[2 - index],
                0);
    sk6812_set_pixel(cube_side_to_index(cube_get_parent_cube()), 0xFF, 0xFF, 0xFF);
    sk6812_show(1);
  }
}

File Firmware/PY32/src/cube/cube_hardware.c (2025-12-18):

#include "cube_hardware.h"

#define DT1_PORT GPIOB
#define DT1_PIN LL_GPIO_PIN_7
#define DT2_PORT GPIOC
#define DT2_PIN LL_GPIO_PIN_1
#define DR1_PORT GPIOA
#define DR1_PIN LL_GPIO_PIN_5
#define DR2_PORT GPIOA
#define DR2_PIN LL_GPIO_PIN_6
#define DB1_PORT GPIOA
#define DB1_PIN LL_GPIO_PIN_1
#define DB2_PORT GPIOA
#define DB2_PIN LL_GPIO_PIN_0
#define DL1_PORT GPIOB
#define DL1_PIN LL_GPIO_PIN_3
#define DL2_PORT GPIOB
#define DL2_PIN LL_GPIO_PIN_4

GPIO_TypeDef *cube_side_to_port1(cube_side_t cube_side)
{
    switch (cube_side)
    {
    case CUBE_TOP:
        return DT1_PORT;
    case CUBE_RIGHT:
        return DR1_PORT;
    case CUBE_BOTTOM:
        return DB1_PORT;
    case CUBE_LEFT:
        return DL1_PORT;
    }
}
uint32_t cube_side_to_pin1(cube_side_t cube_side)
{
    switch (cube_side)
    {
    case CUBE_TOP:
        return DT1_PIN;
    case CUBE_RIGHT:
        return DR1_PIN;
    case CUBE_BOTTOM:
        return DB1_PIN;
    case CUBE_LEFT:
        return DL1_PIN;
    }
}
GPIO_TypeDef *cube_side_to_port2(cube_side_t cube_side)
{
    switch (cube_side)
    {
    case CUBE_TOP:
        return DT2_PORT;
    case CUBE_RIGHT:
        return DR2_PORT;
    case CUBE_BOTTOM:
        return DB2_PORT;
    case CUBE_LEFT:
        return DL2_PORT;
    }
}
uint32_t cube_side_to_pin2(cube_side_t cube_side)
{
    switch (cube_side)
    {
    case CUBE_TOP:
        return DT2_PIN;
    case CUBE_RIGHT:
        return DR2_PIN;
    case CUBE_BOTTOM:
        return DB2_PIN;
    case CUBE_LEFT:
        return DL2_PIN;
    }
}

static void init_data_pin(GPIO_TypeDef *gpio_port, uint32_t gpio_pin, uint8_t input_mode)
{
    LL_GPIO_SetOutputPin(gpio_port, gpio_pin);
    LL_GPIO_InitTypeDef g = {0};
    g.Pin = gpio_pin;
    g.Mode = input_mode ? LL_GPIO_MODE_INPUT : LL_GPIO_MODE_OUTPUT;
    g.Speed = LL_GPIO_SPEED_FREQ_HIGH;
    g.OutputType = LL_GPIO_OUTPUT_OPENDRAIN;
    g.Pull = LL_GPIO_PULL_NO;
    LL_GPIO_Init(gpio_port, &g);
}

static void enable_all_clocks()
{
    LL_IOP_GRP1_EnableClock(LL_IOP_GRP1_PERIPH_GPIOA);
    LL_IOP_GRP1_EnableClock(LL_IOP_GRP1_PERIPH_GPIOB);
    LL_IOP_GRP1_EnableClock(LL_IOP_GRP1_PERIPH_GPIOC);
}

static void init_all_pins()
{
    init_data_pin(DT1_PORT, DT1_PIN, 0);
    init_data_pin(DT2_PORT, DT2_PIN, 1);
    init_data_pin(DR1_PORT, DR1_PIN, 0);
    init_data_pin(DR2_PORT, DR2_PIN, 1);
    init_data_pin(DB1_PORT, DB1_PIN, 0);
    init_data_pin(DB2_PORT, DB2_PIN, 1);
    init_data_pin(DL1_PORT, DL1_PIN, 0);
    init_data_pin(DL2_PORT, DL2_PIN, 1);
}

/**
 * Initializes all data pins used by the cube communication system.
 */
void cube_hardware_init()
{
    enable_all_clocks();
    init_all_pins();
}

/**
 * Returns the opposite side of the given cube side.
 * @param cube_side The side of the cube
 * @return The opposite side of the cube
 */
cube_side_t cube_side_opposite(cube_side_t cube_side)
{
    switch (cube_side)
    {
    case CUBE_TOP:
        return CUBE_BOTTOM;
    case CUBE_RIGHT:
        return CUBE_LEFT;
    case CUBE_BOTTOM:
        return CUBE_TOP;
    case CUBE_LEFT:
        return CUBE_RIGHT;
    default:
        return CUBE_TOP; // Invalid
    }
}
/**
 * Returns the cube side rotated clockwise.
 * @param cube_side The side of the cube
 * @return The cube side rotated clockwise
 */
cube_side_t cube_side_rotate_clockwise(cube_side_t cube_side)
{
    switch (cube_side)
    {
    case CUBE_TOP:
        return CUBE_RIGHT;
    case CUBE_RIGHT:
        return CUBE_BOTTOM;
    case CUBE_BOTTOM:
        return CUBE_LEFT;
    case CUBE_LEFT:
        return CUBE_TOP;
    default:
        return CUBE_TOP; // Invalid
    }
}
/**
 * Returns the cube side rotated counterclockwise.
 * @param cube_side The side of the cube
 * @return The cube side rotated counterclockwise
 */
cube_side_t cube_side_rotate_counterclockwise(cube_side_t cube_side)
{
    switch (cube_side)
    {
    case CUBE_TOP:
        return CUBE_LEFT;
    case CUBE_RIGHT:
        return CUBE_TOP;
    case CUBE_BOTTOM:
        return CUBE_RIGHT;
    case CUBE_LEFT:
        return CUBE_BOTTOM;
    default:
        return CUBE_TOP; // Invalid
    }
}

/**
 * Converts a cube side to the corresponding index of the side
 * @param cube_side The side of the cube
 * @return The index of the side (0-3), or 0xFF if invalid
 */
uint8_t cube_side_to_index(cube_side_t cube_side)
{
    switch (cube_side)
    {
    case CUBE_TOP:
        return 0;
    case CUBE_RIGHT:
        return 1;
    case CUBE_BOTTOM:
        return 2;
    case CUBE_LEFT:
        return 3;
    default:
        return 0xFF; // Invalid
    }
}

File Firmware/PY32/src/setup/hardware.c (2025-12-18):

#include "hardware.h"

/**
 * Enables brown out reset at 3.1-3.2V
 * The device will reset when VDD drops below this threshold (to prevent hanging)
 */
static void enable_bor(void)
{
    FLASH_OBProgramInitTypeDef OBInitCfg;

    /* Read current option bytes */
    HAL_FLASH_OBGetConfig(&OBInitCfg);

    if ((OBInitCfg.USERConfig & (OB_BOR_ENABLE | OB_BOR_LEVEL_3p1_3p2)) != (OB_BOR_ENABLE | OB_BOR_LEVEL_3p1_3p2))
    {
        HAL_FLASH_Unlock();    /* Unlock FLASH */
        HAL_FLASH_OB_Unlock(); /* Unlock Option Bytes */

        /* Prepare only BOR configuration */
        OBInitCfg.OptionType = OPTIONBYTE_USER;
        OBInitCfg.USERType = OB_USER_BOR_EN | OB_USER_BOR_LEV;

        /* Enable BOR with level 3.1-3.2V and iwdg */
        OBInitCfg.USERConfig = OB_BOR_ENABLE | OB_BOR_LEVEL_3p1_3p2;

        /* Program the option bytes */
        HAL_FLASH_OBProgram(&OBInitCfg);

        HAL_FLASH_Lock();    /* Lock FLASH */
        HAL_FLASH_OB_Lock(); /* Lock Option Bytes */

        /* Launch reset to apply */
        HAL_FLASH_OB_Launch();
    }
}

static void SystemClock_Config(void)
{
    LL_RCC_HSI_Enable();
    while (!LL_RCC_HSI_IsReady())
    {
    }

    LL_RCC_SetSysClkSource(LL_RCC_SYS_CLKSOURCE_HSISYS);
    while (LL_RCC_GetSysClkSource() != LL_RCC_SYS_CLKSOURCE_STATUS_HSISYS)
    {
    }

    LL_RCC_SetAHBPrescaler(LL_RCC_SYSCLK_DIV_1);
    LL_RCC_SetAPB1Prescaler(LL_RCC_APB1_DIV_1);

    LL_Init1msTick(24000000);
    LL_SetSystemCoreClock(24000000);
}

/**
 * Initializes the hardware, including HAL, brown out reset, and system clock.
 */
void hardware_init(void)
{
    HAL_StatusTypeDef status = HAL_Init();
    enable_bor();
    SystemClock_Config();
}

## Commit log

2025-11-22 Initial design
    [Module.kicad_pcb, Module.kicad_sch, PogoConnector.kicad_pcb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]
2025-11-22 Prevent accidental short circuit and add basic box 3d model freecad
    [Module.kicad_pcb, Module.kicad_sch, PogoConnector.kicad_pcb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]
2025-11-23 Update PCB
    [Module.kicad_pcb, Module.kicad_sch, PogoConnector.kicad_pcb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]
2025-11-23 Add hall sensor shield
    [Module.kicad_pcb, Module.kicad_sch, PogoConnector.kicad_pcb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]
2025-11-23 Add cadquery for automatic 3d model generation
    [PogoConnector.step, ShieldHallSensor.step, SmartCubeV2.FCStd]
2025-11-23 Update smart cube 3d model
    [PogoConnector.step, ShieldHallSensor.step]
2025-11-23 Add magnet holders
2025-11-23 Add smart cube panel
    [Module.kicad_pcb, PogoConnector.kicad_pcb, ShieldHallSensor.kicad_pcb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]
2025-11-24 Fix 3d model paths
    [Module.kicad_pcb, PogoConnector.kicad_pcb, PogoConnector.step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]
2025-11-24 Fix magnet holder, add todo
2025-11-24 Fix magnet holder wall thickness
2025-11-24 Add power supply (wip) and update panel
    [Module.kicad_pcb, Module.kicad_sch, PogoConnector.kicad_pcb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]
2025-11-27 Finish module, power supply and connector design, panel is wip
    [Module.kicad_pcb, Module.kicad_sch, PogoConnector.kicad_pcb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]
2025-11-28 Finish panel script
    [Module.kicad_pcb, Module.kicad_sch, PogoConnector.kicad_pcb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]
2025-11-28 Update 3d case
    [PogoConnector.step]
2025-11-28 Add Power Supply case
2025-11-28 Fix power supply module offset shape
2025-11-28 Add clip connector
2025-11-28 Fix mistake in pogo pin compression calculation
2025-11-28 Fix broken clip connector
2025-11-30 Fix led pin 1 indicator not visible causing jlcpcb polarity confirmation request email
    [Module.kicad_pcb, SmartCubePanel.kicad_pcb]
2025-11-30 Fix some enclosure tolerances for a better fit
2025-12-08 Implement basic led toggling
2025-12-09 Create led api
2025-12-10 Redesign cube enclosure
2025-12-11 closer magnets lead to bumps in the case so the cases are not flat anymore
2025-12-13 Smaller magnet tolerances
2025-12-13 Add magnet snap fit and smaller box top thickness
2025-12-13 Add button cutouts to power supply enclosure
2025-12-13 Reduce magnet wall thickness
2025-12-13 Add electrolytic bulk capacitors to modules and power supply
    [Module.kicad_pcb, Module.kicad_sch, PowerSupply.kicad_pcb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]
2025-12-14 Replace words with bytes for sending data
    [main.c]
2025-12-14 Fix connecting cubes at the same time not working
    [main.c]
2025-12-14 Add hall sensor initialization
2025-12-17 Update pcbs
    [Module.step, PowerSupply.step]
2025-12-17 Improve clip connector
2025-12-18 Implement new failsafe connection protocol (which later prevents circles in connection graph)
    [cube_connection.c, cube_data_transmission.c, cube_hardware.c]
